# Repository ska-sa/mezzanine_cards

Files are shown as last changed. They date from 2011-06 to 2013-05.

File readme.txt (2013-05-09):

This repository contains the various daughter card designs that mate with ROACH2's high-speed MGT mezzanine connector.

Contents:
SFPP -- a 4 x SFP+ 10GbE connector board, driven by two dual Vitesse PHYs.
CX4  -- a 3 x CX4 port connector board, purely passive. Due to rear panel space constraints, the fourth port is available as a header for internal connection.

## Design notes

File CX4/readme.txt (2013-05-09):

This is the repository for the CX4 mezzanine card used by ROACH2. 

Directory contents:
design -- PCB and schematic
release -- manufacturing pack, including gerbers.

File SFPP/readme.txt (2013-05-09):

This is the design repository for the 4x SFP+ 10GbE mezzanine card, as used on ROACH2.

Directory structure:
design -- Contains the schematic and PCB layout, along with some documentation used during design.
release -- manufacturing packs for the various revision boards.

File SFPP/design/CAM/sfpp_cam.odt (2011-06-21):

PCB Specification

Date: | 15th June 2011
Company: | SKA SA
Billing Address: | 17 Baker St, Rosebank, Johannesburg, South Africa PO Box 522940, Saxonwold, 2132
Postal Address: | SKA SA, 3rd Floor, The Park, Park Road, Pinelands, 7405, South Africa
Contact: | David George | Email: | david.george@ska.ac.za
| | Tel: | +27 11 442 2434
| Philip Gibbs | Email: | philip.gibbs@ska.ac.za
| | Tel: | +27 21 506 7363

Board name: | SFP+ Mezzanine Card
Revision: | 0
Release: | PRELIM

PCB Details

PCB Specifications: | IPC 6012 Class 2
Finished Board Size: | 90 x 107.4 mm
PCB Type: | Multi-layer
Layer Count: | 8
Dielectric: | All dielectric layers to be Isola 370HR high temperature laminate
Nominal board Thickness: | 1.6mm; tolerance +/-10%
Hole tolerance: | +3mil for vias; +/- 3mil for component holes and slots
Finish: | ENIG
Soldermask: | Green
Silkscreen: | White
Minimum clearance: | 4 mil in BGA areas, 6 mil otherwise
Handling rails: | TBD
Panelisation: | TBD

PCB Stackup

Layer | # | Copper (oz) | Dieletric (mil)** | Filename
Pastemask Top | | - | - | sfpp.GTP
Silkscreen Top | | - | - | sfpp.GTO
Soldermask Top | | - | - | sfpp.GTS
Signal Top | 1 | 0.5 | | sfpp.GTL
| | | 5mil
Ground 1 | 2 | 0.5 | | sfpp.GP1
| | | 8mil
Signal 1 | 3 | 0.5 | | sfpp.G1
| | | 8mil
Power 1 | 4 | 0.5 | | sfpp.GP2
| | | *
Power 2 | 5 | 0.5 | | sfpp.G2
| | | 8mil
Signal 2 | 6 | 0.5 | | sfpp.GP3
| | | 8mil
Ground 2 | 7 | 0.5 | | sfpp.GP4
| | | 5mil
Signal Bottom | 8 | 0.5 | | sfpp.GBL
Soldermask Bottom | | - | - | sfpp.GBS
Silkscreen Bottom | | - | - | sfpp.GBO
Pastemask Bottom | | - | - | sfpp.GBP

* Thickness may be adjusted to achieve nominal total thickness previously specified, to satisfy impedance targets and to accommodate manufacturing processes.

Impedance Controlled Traces

All impedance matching to +/- 10%

Microstrip

Layers: | Signal Top (#1), Signal Bottom (#8)
Target Impedance: | 50 ohm
Trace thickness: | 8 mil

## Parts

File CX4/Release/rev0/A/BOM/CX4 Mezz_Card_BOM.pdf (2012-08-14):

Comment | Description | Designator | Footprint | Manufacturer | PartNum | Quantity
0.01uF | 0.01uF, Ceramic Capacitor | C2, C6, C7, C11, C15, C16,
| | C20, C24, C25 | CAPC1005X55L | MURATA | GRM155R71E103KA01D | 9
0.1uF | 0.1uF, Ceramic Capacitor | C3, C8, C9, C10, C12, C17,
C18, C19, C21, C26, C27, C28 CAPC1005X60L | VENKEL | C0402X7R160-104KN | 12
4.7uF | 4.7uF, Ceramic Capacitor | C4, C13, C22 | CAPC2012X127L | MURATA | GRM21BR61E475KA12K | 3
22uF | 22uF, Ceramic Capacitor | C5, C14, C23, C29, C30 | CAPC3225X270L | MURATA | GRM32ER61E226ME15L | 5
SML-LX1206IC-TR | Red, Surface mount, LED, 1206 | DS1, DS2, DS3 | LEDC3216X120N | LUMEX | SML-LX1206IC-TR | 3
QFSS-064-04.25-L-D-A-DP | Shielded, 64-Differential Pair, Rugged High-Speed
| Terminal Strip, 0.635mm Pitch | J1 | SAMTEC_QFSS-064-04.25-L-
| | | D-DP-A | SAMTEC | QFSS-064-04.25-L-D-A-DP | 1
FCN-268D008-G/2D | CX4/Infiniband 4 channel Socket Connector | J2, J3, J4 | FCN-268D008-G | Fujitsu | FCN-268D008-G/0D | 3
SMT Header, 2mm 10X2 | 2x10, 2mm Pitch, Male Header, Surface Mount | P1, P2, P3 | HEADER 10x2, SMT, 2mm | SAMTEC | TMMH-110-05-T-DV | 3
150R | 150R, 1.1mm x 0.5mm, Thick Film Resistor | R1, R5, R11 | RESC1005X40L | ROYALOHM | 0402WGJ0151T1E | 3
5K1 | 5K1, 1.1mm x 0.5mm, Thick Film Resistor | R2, R8, R12 | RESC1005X40L | ROYALOHM | 0402WAJ0512T1E | 3
3K9 | 3K9, 1.1mm x 0.5mm, Thick Film Resistor | R3, R6, R9, R13, R15, R17 | RESC1005X40L | ROYALOHM | 0402WGJ0392T1E | 6
6K8 | 6K8, 1.1mm x 0.5mm, Thick Film Resistor | R4, R10, R14 | RESC1005X40L | ROYALOHM | 0402WGJ0682T1E | 3
10K | 10K, 1.1mm x 0.5mm, Thick Film Resistor | R7, R16, R18 | RESC1005X40L | ROYALOHM | 0402WGJ0103T1E | 3
CCLD-023-25-156.250 | 156.25 MHz, Low-Jitter Differential LVDS Clock Oscillator | U1 | CCLD-023X-XX-XXX_XXX | Crystek | CCLD-023-25-156.250 | 1
MAX9032AKA | Dual Single-Supply Comparator | U2, U5, U7 | TSOT-23-8 | MAXIM | MAX9032AKA | 3
SN74AHC1G08DCKR | Single 2-Input Positive-AND Gate | U3, U6, U8 | SC70-5 | Texas Instruments | SN74AHC1G08DCKR | 3
TPS2031D | Power-Distribution Switch | U4, U9, U10 | SOIC150-8_N | Texas Instruments | TPS2031D | 3

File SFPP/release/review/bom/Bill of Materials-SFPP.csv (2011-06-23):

POD number | Manufacturer | PartNum | Description | Designator | Quantity | Rating | Tolerance | Value
TRANS-NFET-0 | Fairchild Semiconductor | BSS138 | N-Channel Logic Level Enhancement Mode Field Effect Transistor | Q1, Q4, Q5 | 3 | 0.22A
RESN-CLK-6 | Kyocera | KC7050P156.250L30E00 | 156.25 MHz, Low-Jitter Differential LVDS Clock Oscillator, 7x5mm surface mount | U6, U8 | 2
RES-TF-46 | STACKPOLE | RMC0402FT2K87 | 2K87, 1.1mm x 0.5mm, Thick Film Resistor | R6 | 1 | 0.0625W | 1% | 2k87
RES-TF-45 | STACKPOLE | RMC0402FT3K57 | 3K57, 1.1mm x 0.5mm, Thick Film Resistor | R5 | 1 | 0.0625W | 1% | 3k57
RES-TF-36 | ROYALOHM | 0402WGF2K49T1E | 2K49, 1.1mm x 0.5mm, Thick Film Resistor | R2, R45 | 2 | 0.0625W | 1% | 2K49
RES-TF-19 | ROYALOHM | 0402WGF0201T1E | 200R, 1.1mm x 0.5mm, Thick Film Resistor | R36, R37, R38, R39 | 4 | 0.0625W | 1% | 200R
RES-TF-13 | ROYALOHM | 0402WGF4991T1E | 4K99, 1.1mm x 0.5mm, Thick Film Resistor | R3, R46 | 2 | 0.0625W | 1% | 4K99
RES-TF-7 | ROYALOHM | 0402WGJ0332T1E | 3K3, 1.1mm x 0.5mm, Thick Film Resistor | R7, R8, R9, R10, R11, R12, R13, R14, R15, R16, R17, R18, R20, R21, R22, R23, R24, R25, R26, R27, R28, R29, R30, R31, R32, R33, R34, R35, R40, R41, R42, R43, R47, R48, R49, R50, R51, R52, R53, R54, R55, R56, R57, R58, R59, R60, R61, R62, R63 | 49 | 0.0625W | 5% | 3K3
RES-TF-5 | ROYALOHM | 0402WGJ0103T1E | 10K, 1.1mm x 0.5mm, Thick Film Resistor | R1, R4, R44 | 3 | 0.0625W | 5% | 10K
RES-TF-0 | ROYALOHM | 0402WG00000T1E | 0R, 1.1mm x 0.5mm, Thick Film Resistor | R19 | 1 | 0.0625W | 0% | 0R
OPTO-LPIPE-1 | Dialight | 515-1094F | 2-High, press-fit, 3mm round, light-pipe | DS1, DS2 | 2 | NA
OPTO-LED-0 | LUMEX | SML-LX1206GC-TR | Green, Surface mount, LED, 1206 | DS3, DS4, DS5, DS6 | 4 | 20mA
IND-FB-1 | Murata | BLM31PG121SN1 | 120 Ohm, Chip Ferrite Brad | L1, L2, L3, L4, L5, L6 | 6 | 3000mA | 25% | 120R
IC-REG-5 | Texas Instruments | TPS74401 | 3.0A Ultra-LDO with Programmable Soft-Start | U3, U4, U9 | 3
IC-PHY-2 | Vitesse | VSC8488XJU | DualChannel WAN/LAN/Backplane XAUI to SFP+/KR Transceiver | U1, U2 | 2
IC-MEM-5 | Atmel | AT24C1024BN-SH-B | 1M, SOIC-8, Serial EEPROM | U5, U7 | 2
CONN-PCB-27 | Molex | 74441-0001 | 20 Circuit, 0.8mm pitch SFP+ host connector | P2, P3, P4, P5 | 4
CONN-PCB-26 | Molex | 0747540420 | SFP+ 1X4 Cage Assembly | P1 | 1
CONN-PCB-19 | SAMTEC | QFSS-064-04.25-L-D-A-DP | Shielded, 64-Differential Pair, Rugged High-Speed Terminal Strip, 0.635mm Pitch | J1 | 1
CONN-PCB-16 | SAMTEC | TSM-107-01-TM-DV-P | 2x7, 2.54 mm Pitch, Male Header | P6 | 1
CAP-CER-13 | TDK | C3225X5R0J107M | 100uF, 1210, Ceramic Capacitor | C33, C42, C73 | 3 | 6.3V | 20% | 100uF
CAP-CER-8 | MURATA | GRM21BR61C105KA01L | 1uF, Ceramic Capacitor | C71, C72, C74, C75, C76, C77, C78, C112, C113, C115, C116, C117, C118, C119 | 14 | 16V | 10% | 1uF
CAP-CER-6 | MURATA | GRM155R71E103KA01D | 0.01uF, Ceramic Capacitor | C38, C44, C128 | 3 | 25V | 10% | 0.01uF
CAP-CER-5 | MURATA | GRM32DR61E106KA12L | 10uF, Ceramic Capacitor | C34, C36, C37, C39, C40, C43, C124, C126, C127 | 9 | 25V | 10% | 10uF
CAP-CER-3 | MURATA | GRM21BR61E475KA12K | 4.7uF, Ceramic Capacitor | C45, C46, C47, C48, C56, C57, C58, C61, C82, C83, C84, C85, C94, C95, C103, C104 | 16 | 25V | 10% | 4.7uF
CAP-CER-1 | VENKEL | C0402X7R160-104KN | 0.1uF, Ceramic Capacitor | C1, C2, C3, C4, C5, C6, C7, C8, C9, C10, C11, C12, C13, C14, C15, C16, C17, C18, C19, C20, C21, C22, C23, C24, C25, C26, C27, C28, C29, C30, C31, C32, C35, C41, C49, C50, C51, C52, C53, C54, C55, C59, C60, C62, C63, C64, C65, C66, C67, C68, C69, C70, C79, C80, C81, C86, C87, C88, C89, C90, C91, C92, C93, C96, C97, C98, C99, C100, C101, C102, C105, C106, C107, C108, C109, C110, C111, C114, C120, C121, C122, C125, C129, C130, C131 | 85 | 16V | 10% | 0.1uF

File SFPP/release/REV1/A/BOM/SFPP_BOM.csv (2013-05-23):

POD number | Manufacturer | PartNum | Description | Designator | Tolerance | Value | Quantity
CAP-CER-1 | VENKEL | C0402X7R160-104KN | 0.1uF, Ceramic Capacitor | C1, C2, C3, C4, C5, C6, C7, C8, C9, C10, C11, C12, C13, C14, C15, C16, C17, C18, C19, C20, C21, C22, C23, C24, C25, C26, C27, C28, C29, C30, C31, C32, C35, C41, C49, C50, C51, C52, C53, C54, C55, C59, C60, C62, C63, C64, C65, C66, C67, C68, C69, C70, C79, C80, C82, C85, C86, C87, C88, C89, C90, C91, C92, C93, C96, C97, C98, C99, C100, C101, C102, C105, C106, C108, C110, C111, C114, C120, C121, C125, C129, C130, C131, C133, C136, C141, C144 | 10% | 0.1uF | 87
CAP-CER-13 | TDK | C3225X5R0J107M | 100uF, 1210, Ceramic Capacitor | C33, C42, C73, C145 | 20% | 100uF | 4
CAP-CER-5 | MURATA | GRM32DR61E106KA12L | 10uF, Ceramic Capacitor | C34, C36, C37, C39, C40, C43, C124, C126, C127, C142, C143, C146 | 10% | 10uF | 12
CAP-CER-6 | MURATA | GRM155R71E103KA01D | 0.01uF, Ceramic Capacitor | C38, C44, C81, C122, C128, C139, C140, C147 | 10% | 0.01uF | 8
CAP-CER-3 | MURATA | GRM21BR61E475KA12K | 4.7uF, Ceramic Capacitor | C45, C46, C47, C48, C56, C57, C58, C61, C83, C84, C94, C95, C103, C104, C123, C132, C134, C135, C137, C138 | 10% | 4.7uF | 20
CAP-CER-8 | MURATA | GRM21BR61C105KA01L | 1uF, Ceramic Capacitor | C71, C72, C74, C75, C76, C77, C78, C112, C113, C115, C116, C117, C118, C119 | 10% | 1uF | 14
CAP-CER-4 | MURATA | GRM155R61H102KA01D | 1000pF, Ceramic Capacitor | C107, C109 | 10% | 1000pF | 2
OPTO-LPIPE-1 | Dialight | 515-1094F | 2-High, press-fit, 3mm round, light-pipe | DS1, DS2 |  |  | 2
OPTO-LED-0 | LUMEX | SML-LX1206GC-TR | Green, Surface mount, LED, 1206 | DS3, DS4, DS5, DS6 |  |  | 4
CONN-PCB-19 | SAMTEC | QFSS-064-04.25-L-D-A-DP | Shielded, 64-Differential Pair, Rugged High-Speed Terminal Strip, 0.635mm Pitch | J1 |  |  | 1
IND-FB-1 | Murata | BLM31PG121SN1 | 120 Ohm, Chip Ferrite Brad | L1, L2, L3, L4, L5, L6, L7, L8, L9, L10 | 25% | 120R | 10
IND-FB-0 | Murata | BLM21BD601SN1 | 600 Ohm, Chip Ferrite Bead | L11 | 25% | 600R | 1
CONN-PCB-26 | Molex | 747540420 | SFP+ 1X4 Cage Assembly | P1 |  |  | 1
CONN-PCB-27 | Molex | 74441-0001 | 20 Circuit, 0.8mm pitch SFP+ host connector | P2, P3, P4, P5 |  |  | 4
CONN-PCB-16 | SAMTEC | TSM-107-01-TM-DV-P | 2x7, 2.54 mm Pitch, Male Header | P6 |  |  | 1
TRANS-NFET-0 | Fairchild Semiconductor | BSS138 | N-Channel Logic Level Enhancement Mode Field Effect Transistor | Q1, Q2, Q3, Q4, Q5, Q6, Q7 |  |  | 7
RES-TF-5 | ROYALOHM | 0402WGJ0103T1E | 10K, 1.1mm x 0.5mm, Thick Film Resistor | R1, R4, R44, R66 | 5% | 10K | 4
RES-TF-36 | ROYALOHM | 0402WGF2K49T1E | 2K49, 1.1mm x 0.5mm, Thick Film Resistor | R2, R45 | 1% | 2K49 | 2
RES-TF-13 | ROYALOHM | 0402WGF4991T1E | 4K99, 1.1mm x 0.5mm, Thick Film Resistor | R3, R46 | 1% | 4K99 | 2
RES-TF-45 | STACKPOLE | RMC0402FT3K57 | 3K57, 1.1mm x 0.5mm, Thick Film Resistor | R 5 | 1% | 3k57 | 1
RES-TF-46 | STACKPOLE | RMC0402FT2K87 | 2K87, 1.1mm x 0.5mm, Thick Film Resistor | R 6 | 1% | 2k87 | 1
RES-TF-7 | ROYALOHM | 0402WGJ0332T1E | 3K3, 1.1mm x 0.5mm, Thick Film Resistor | R7, R8, R9, R10, R11, R12, R13, R14, R15, R16, R17, R18, R20, R21, R22, R23, R24, R25, R26, R27, R28, R29, R30, R31, R32, R33, R34, R35, R36, R37, R38, R39, R40, R41, R42, R43, R47, R48, R49, R50, R51, R52, R53, R54, R55, R56, R57, R58, R59, R60, R61, R62, R63, R70, R71, R72, R73 | 5% | 3K3 | 57
RES-TF-0 | ROYALOHM | 0402WG00000T1E | 0R, 1.1mm x 0.5mm, Thick Film Resistor | R19, R65 | 0% | 0R | 2
RES-TF-14 | ROYALOHM | 0402WGF0101T1E | 100R, 1.1mm x 0.5mm, Thick Film Resistor | R64, R69 | 1% | 100R | 2
RES-TF-55 | ROYALOHM | 0402WGF3601T1E | 3K6, 1.1mm x 0.5mm, Thick Film Resistor | R 67 | 1% | 3K6 | 1
RES-TF-54 | ROYALOHM | 0402WGF1601T1E | 1K6, 1.1mm x 0.5mm, Thick Film Resistor | R 68 | 1% | 1K6 | 1
IC-PHY-2 | Vitesse | VSC8488XJU | DualChannel WAN/LAN/Backplane XAUI to SFP+/KR Transceiver | U1, U2 |  |  | 2
IC-REG-5 | Texas Instruments | TPS74401RGW | 3.0A Ultra-LDO with Programmable Soft-Start | U3, U4, U9, U10 |  |  | 4
IC-LOG-14 | Micrel | SY89832UMG | 2.5 C Ultra-precision 1:4 LVDS Fanout Buffer/Translator with Interal Termination | U6 |  |  | 1
RESN-CLK-4 | Crystek | CCLD-023-25-156.250 | 2.5V 156.25 MHz, Low-Jitter Differential LVDS Clock Oscillator | U8 |  |  | 1
IC-MEM-5 | Atmel | AT24C1024BN-SH-B | 1M, SOIC-8, Serial EEPROM | U5, U7 |  |  | 2 | Discontinued
 | Atmel | AT24CM01-SSHM-B |  | U5, U7 |  |  | 2 | New Part

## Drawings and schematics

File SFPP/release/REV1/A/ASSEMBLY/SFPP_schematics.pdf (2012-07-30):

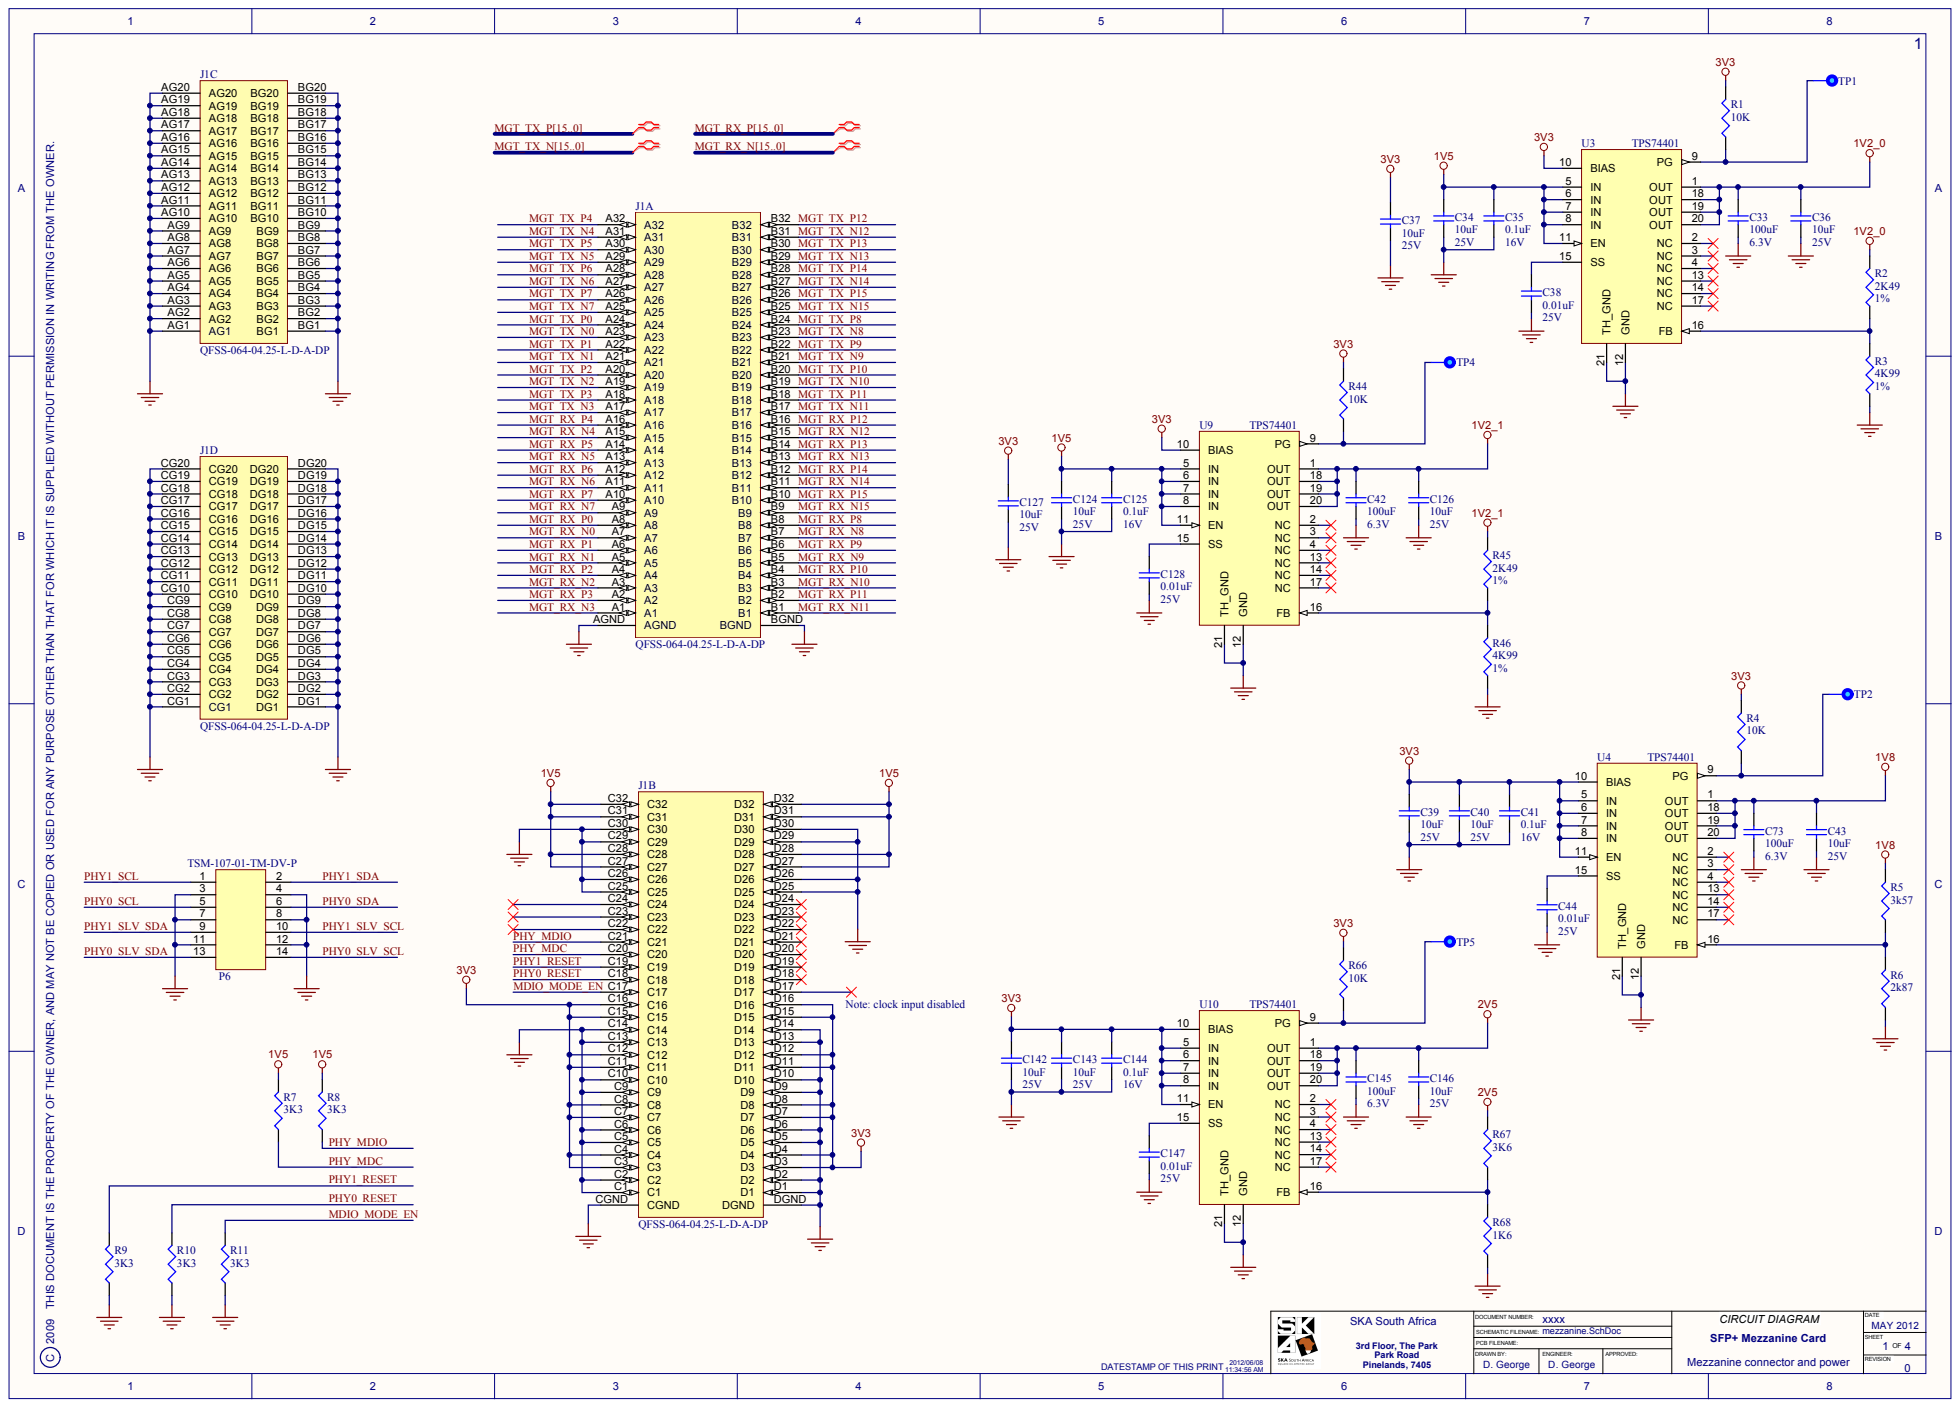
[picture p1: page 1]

2009 THIS DOCUMENT IS THE PROPERTY OF THE OWNER, AND MAY NOT BE COPIED OR USED FOR ANY PURPOSE OTHER THAN THAT FOR WHICH IT IS SUPPLIED WITHOUT PERMISSION IN WRITING FROM THE OWNER. C

EN 11 | 2

EN 11

Note: clock input disabled

D O C U M E N T N U M B E R : x x x x | CIRCUIT DIAGRAM | D A T E M A Y 2

mezzanine.SchDoc APPRO S C H E M A T I C F ILE N A M E : P C B F ILE N A M E : | S H E E T O F

D RAWN B Y : | E N G I N E E R : | V E D : | R E V I S I O N

8 DATESTAMP OF THIS PRINT

zanine connector and power

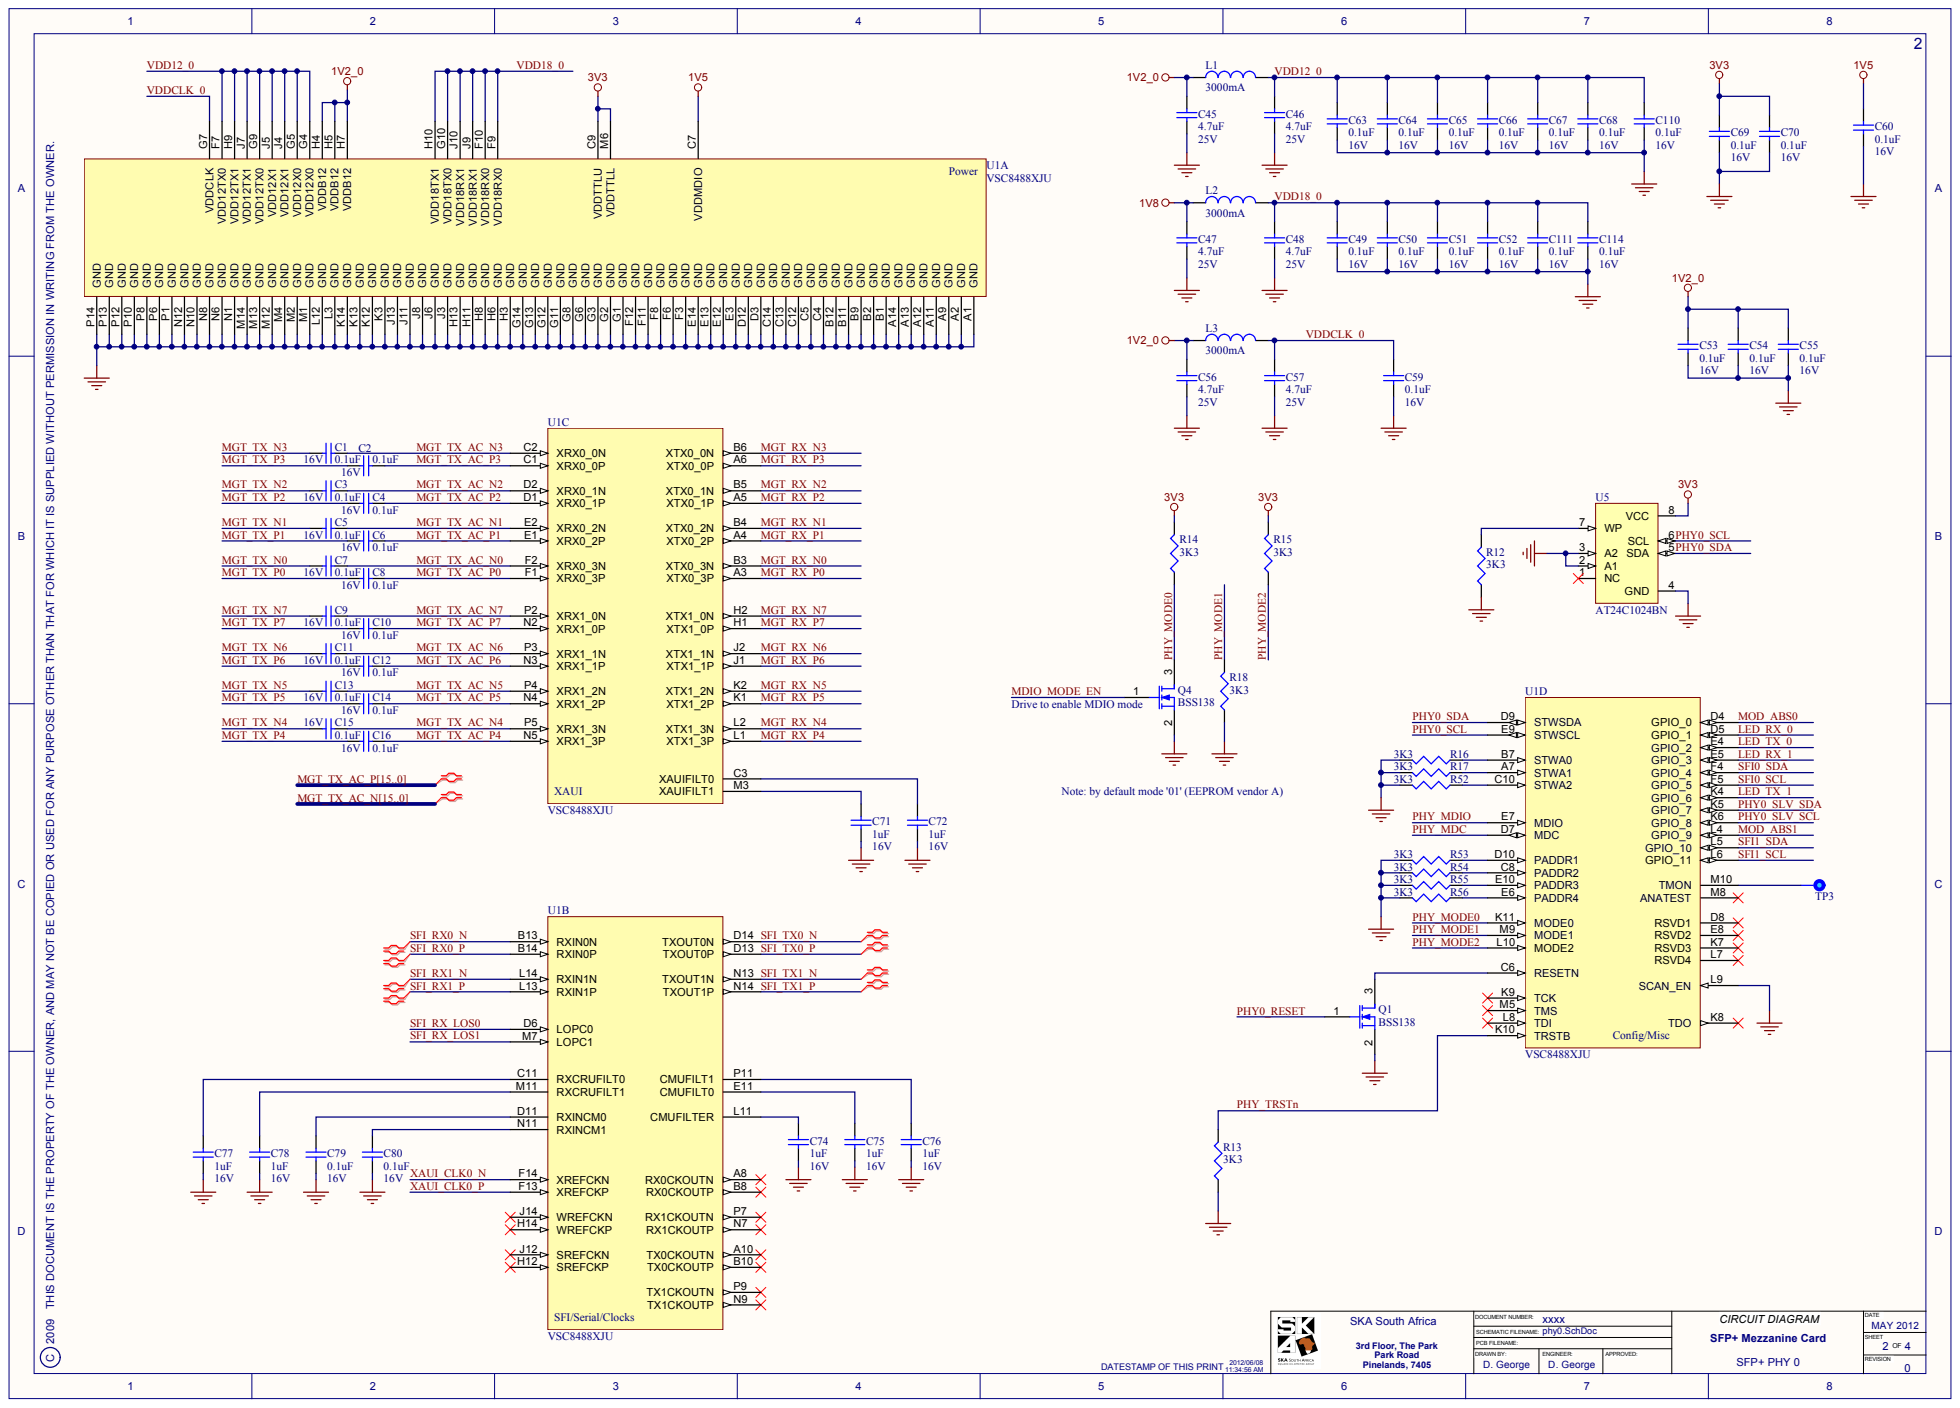
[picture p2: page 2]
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

MDIO_MODE_EN
Drive to enable MDIO mode

Note: by default mode '01' (EEPROM vendor A)

DOCUMENT NUMBER: xxxx | DATE MAY 2012

phy0.SchDoc SCHEMATIC FILENAME: PCB FILENAME: | SHEET OF 4

APPROVED: | REVISION

2012/06/08 DATESTAMP OF THIS PRINT

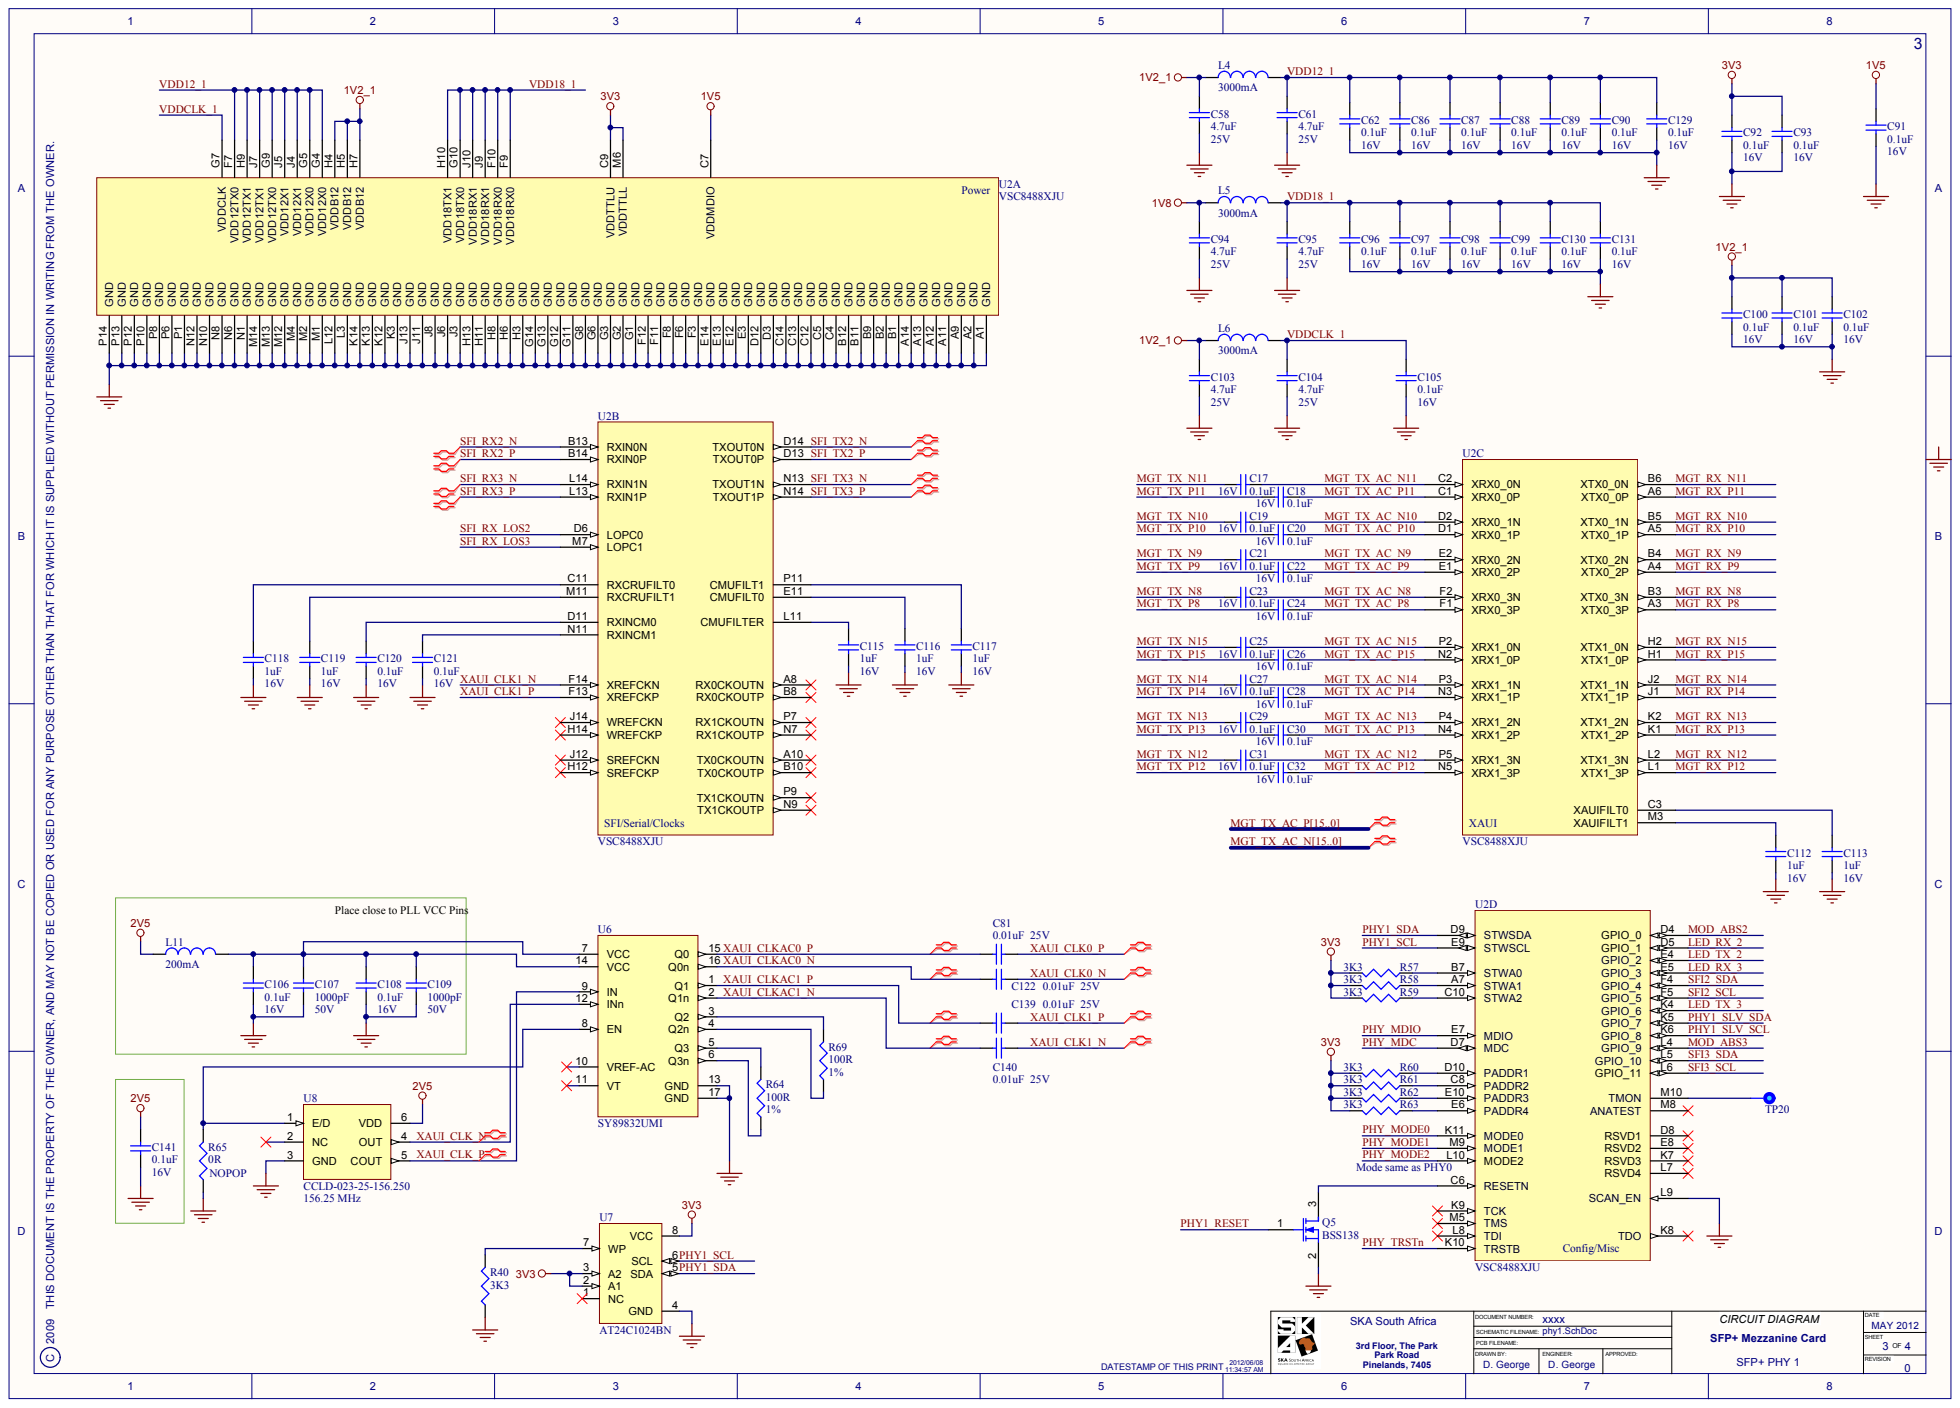
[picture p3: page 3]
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

Place close to PLL VCC Pins

NC 2 OUT | 4 | XAUI_CLK_N
GND 3 | | XAUI_CLK_P

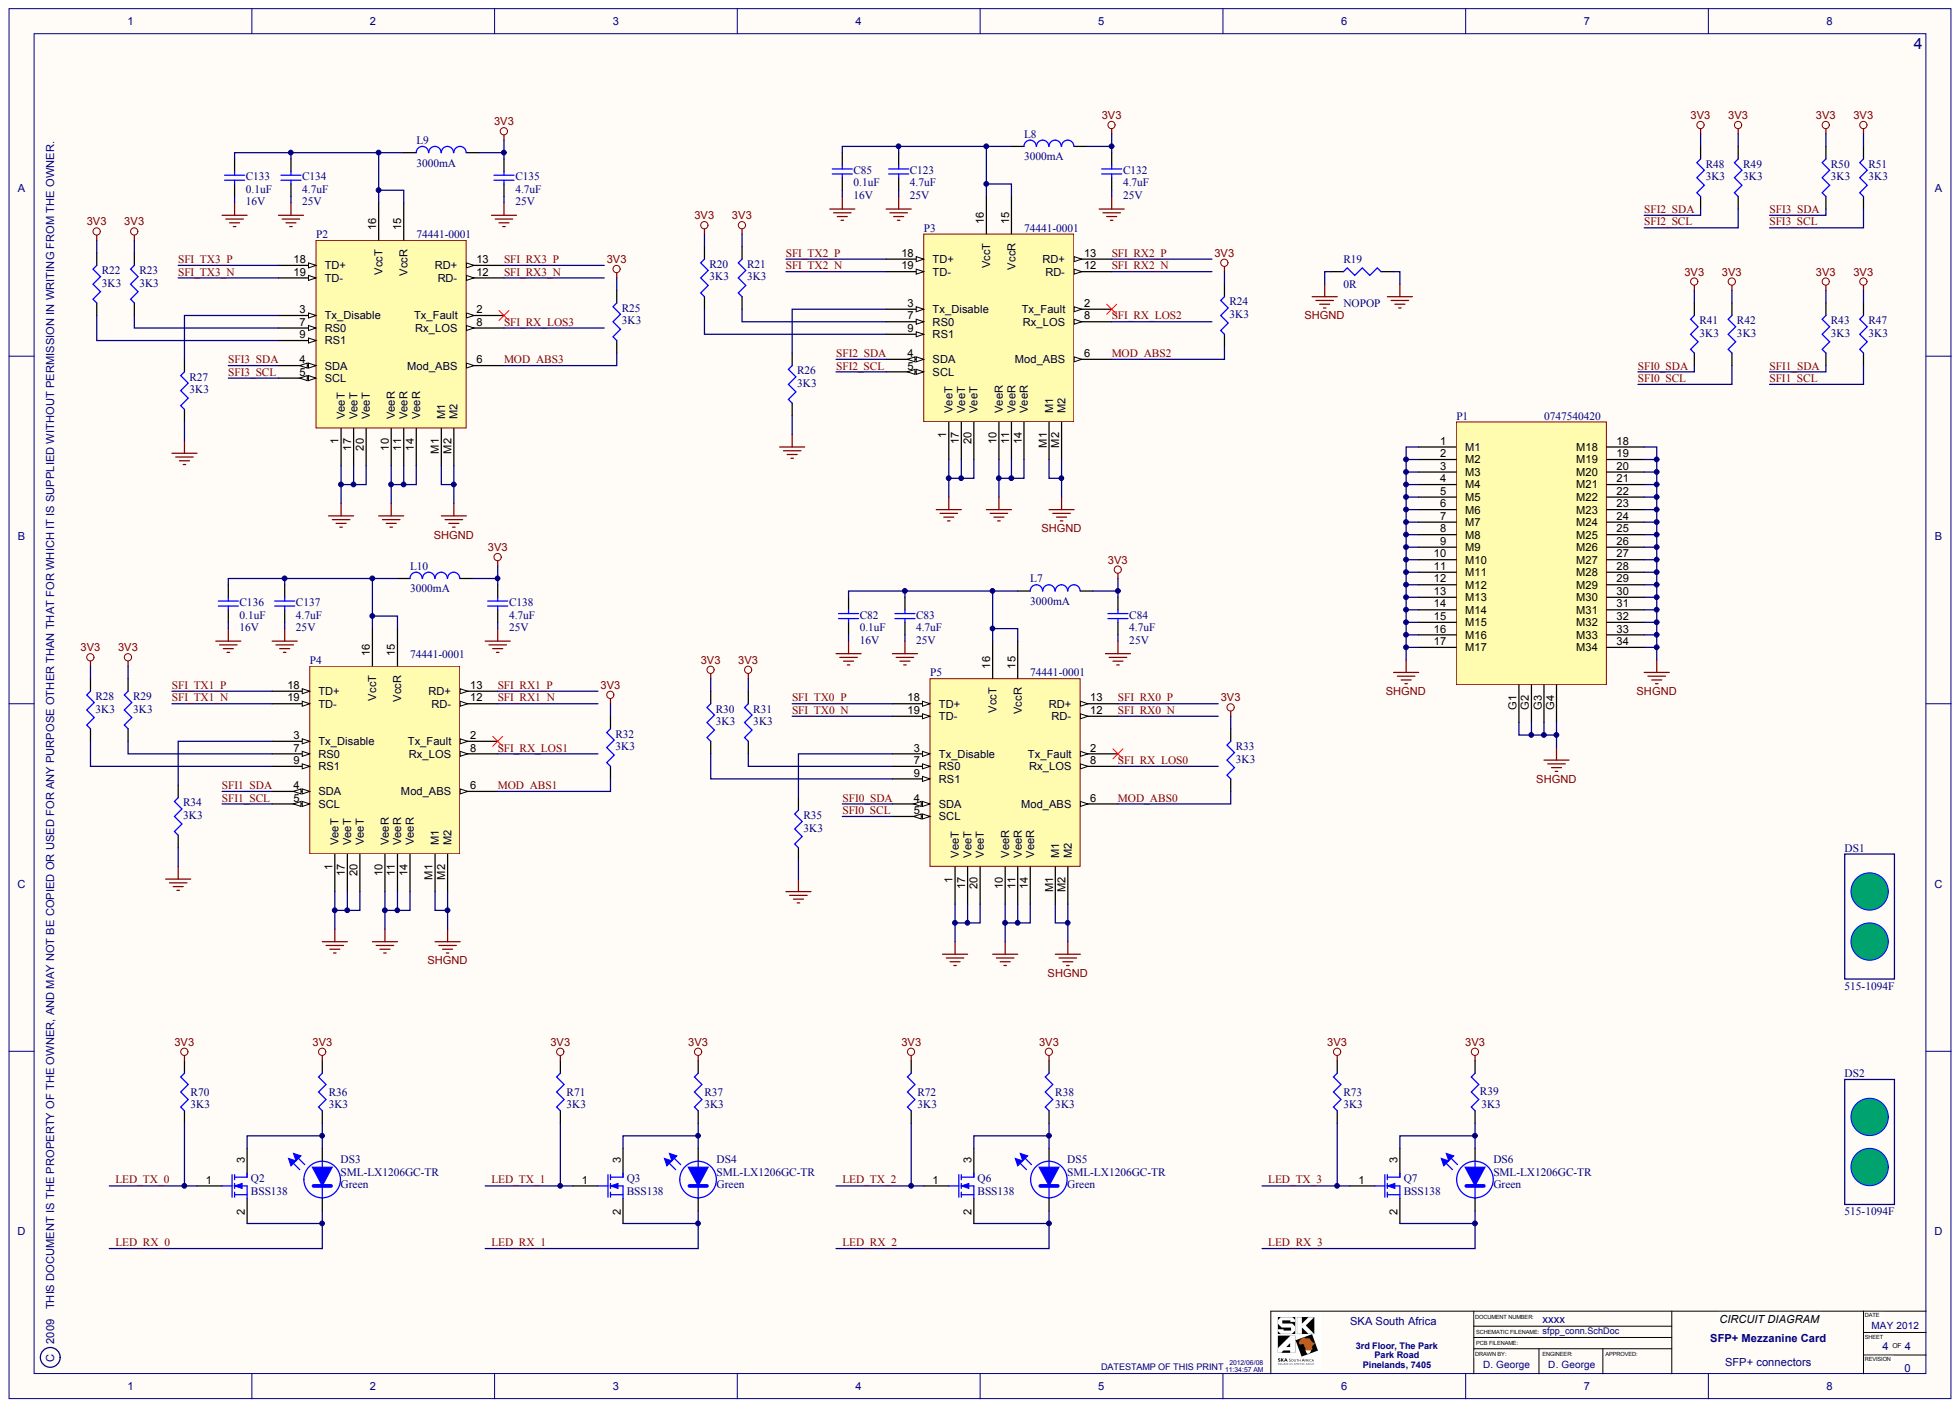
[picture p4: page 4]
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

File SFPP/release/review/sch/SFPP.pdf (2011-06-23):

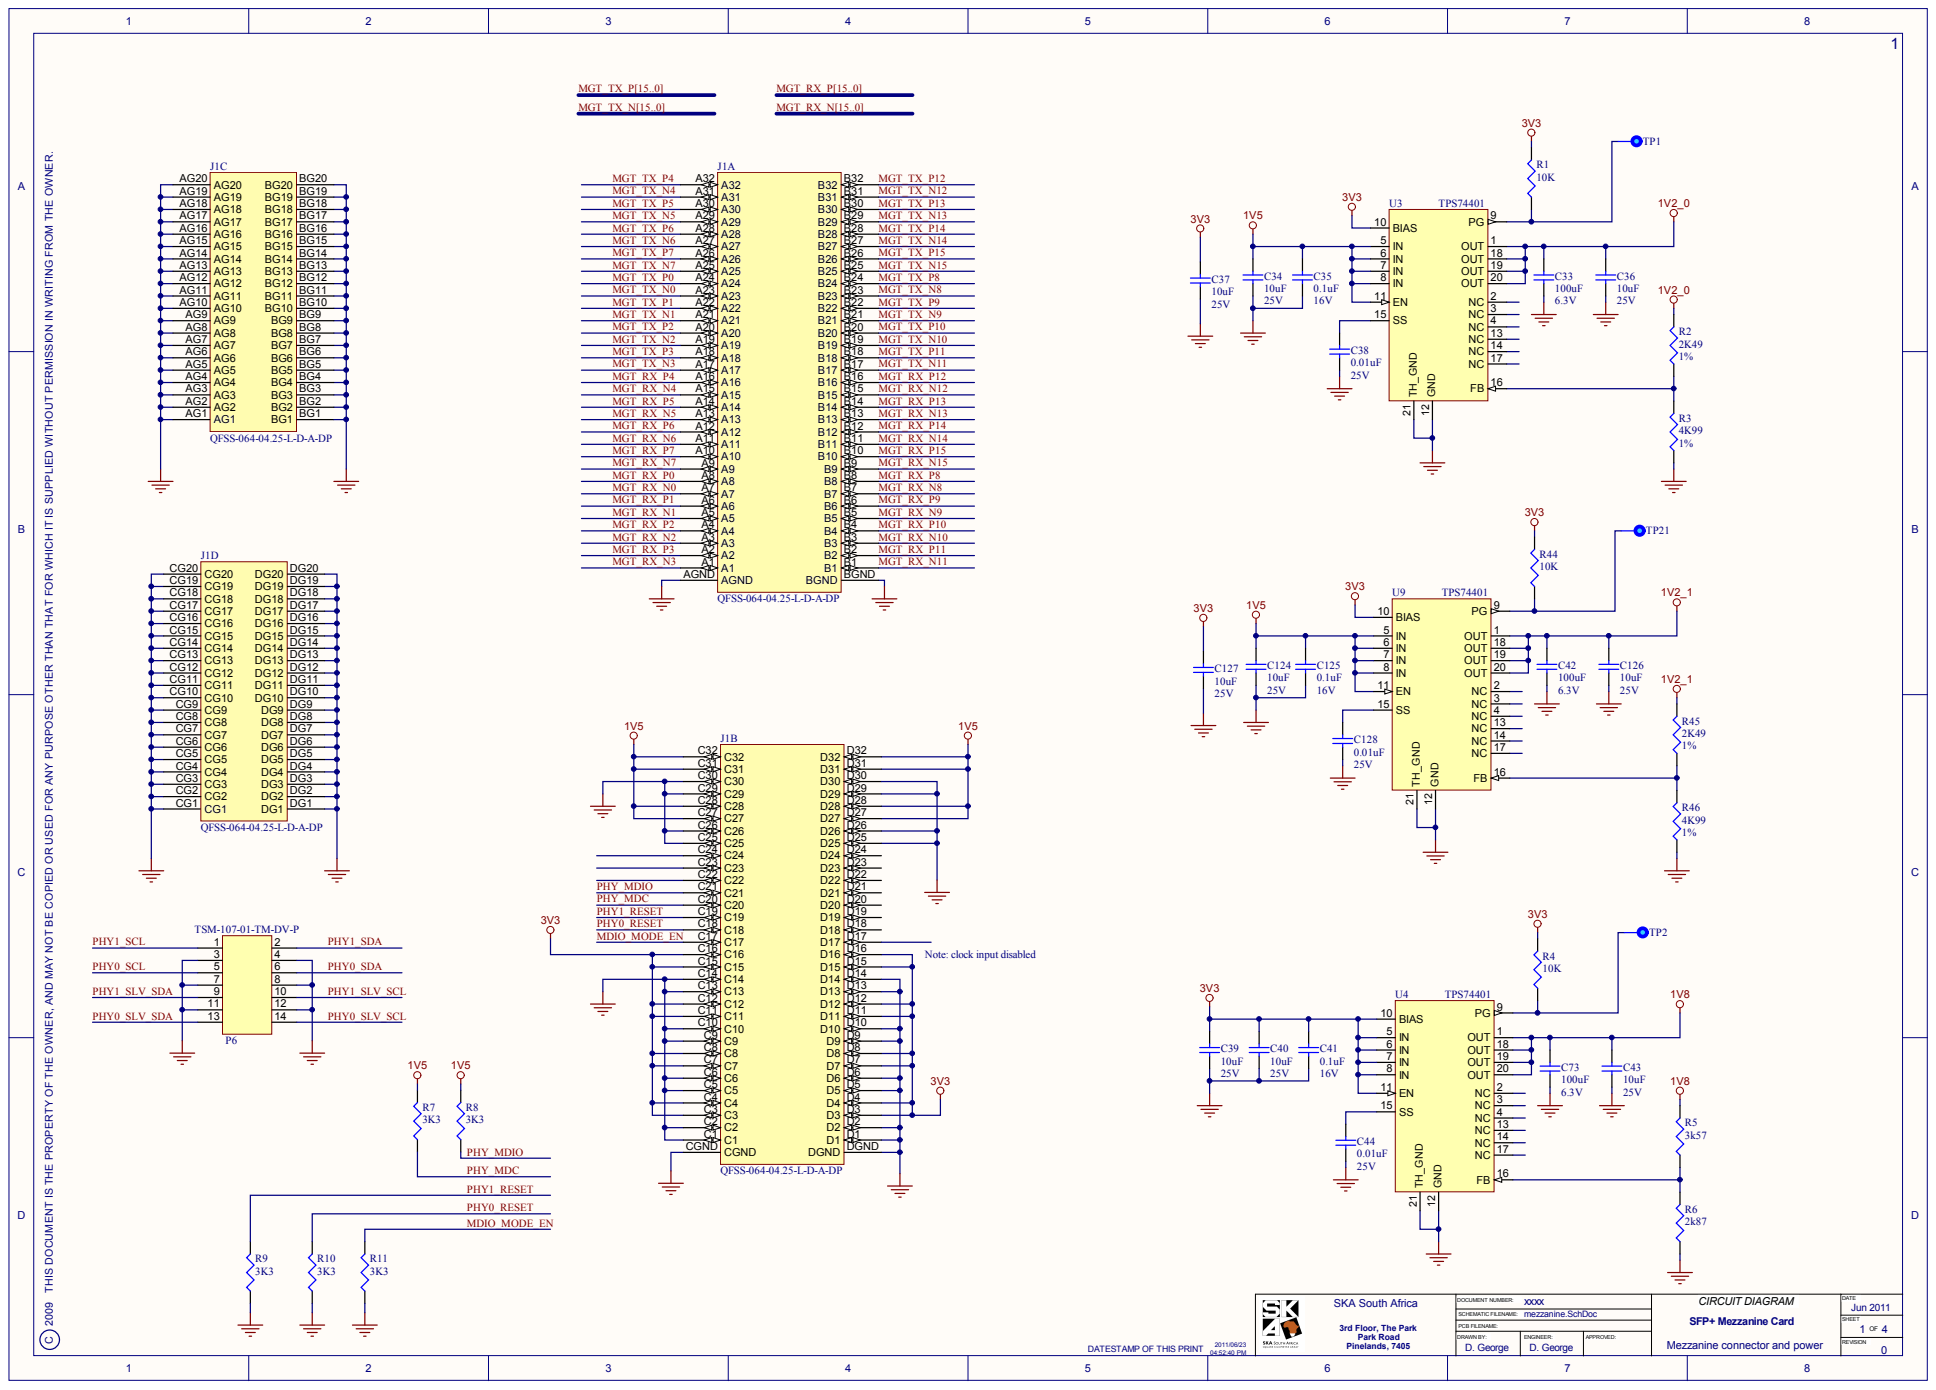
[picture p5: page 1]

2009 THIS DOCUMENT IS THE PROPERTY OF THE OWNER, AND MAY NOT BE COPIED OR USED FOR ANY PURPOSE OTHER THAN THAT FOR WHICH IT IS SUPPLIED WITHOUT PERMISSION IN WRITING FROM THE OWNER. C

EN 11 | 2

U MEN T N BER xxxx | C UI DIA G RA M | D AT E Ju

me z z a nin e . Sch o c HEM C F L AM : | S HEE T OF

RAW N BY: | NGI EER | APP VED | R V I O N

anine connector and powe

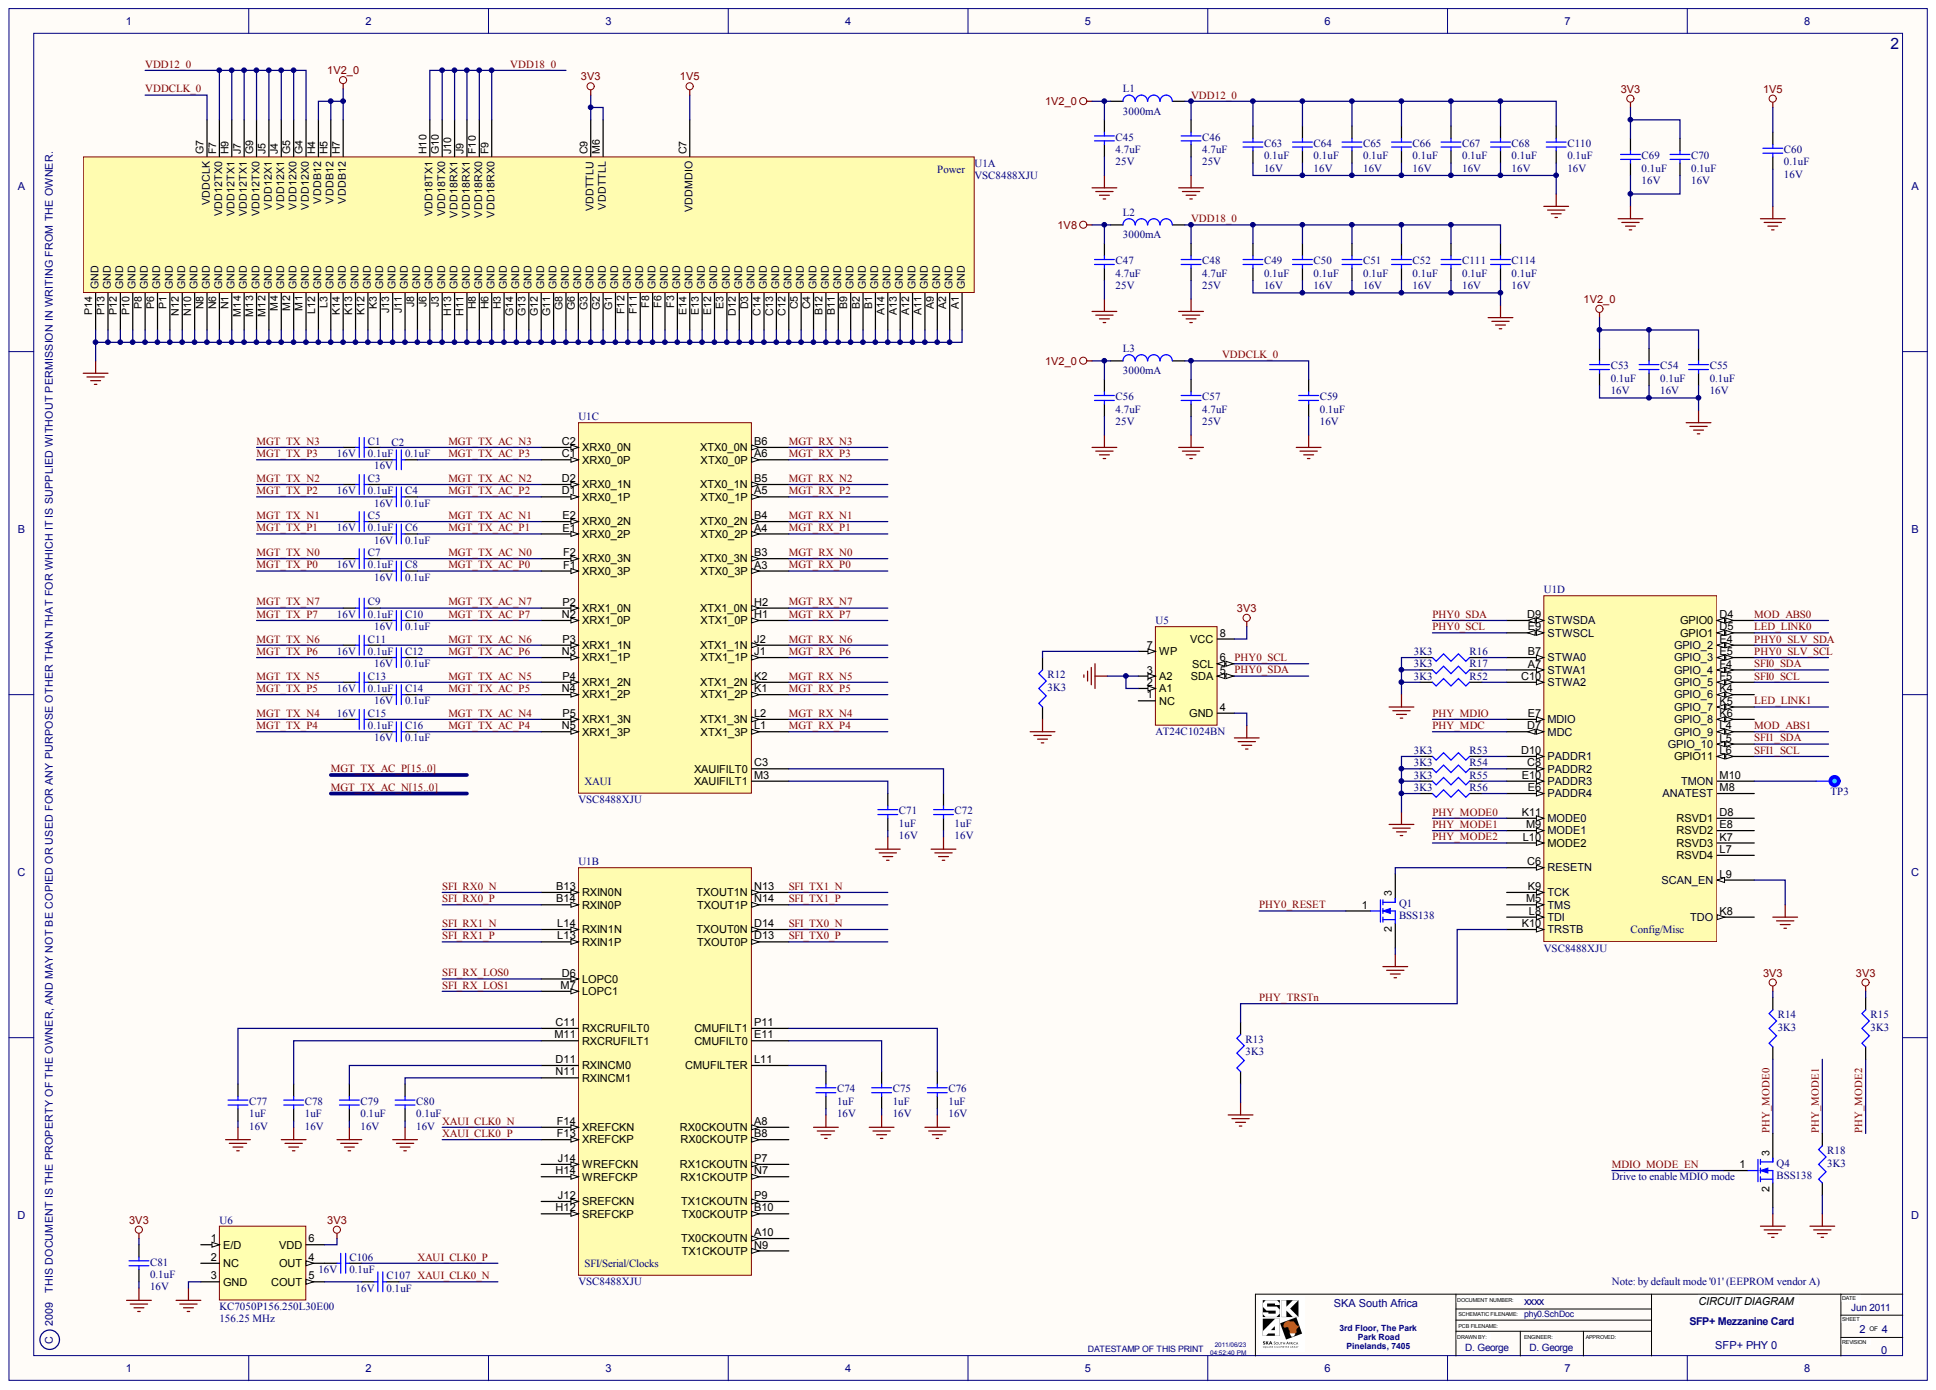
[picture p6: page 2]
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

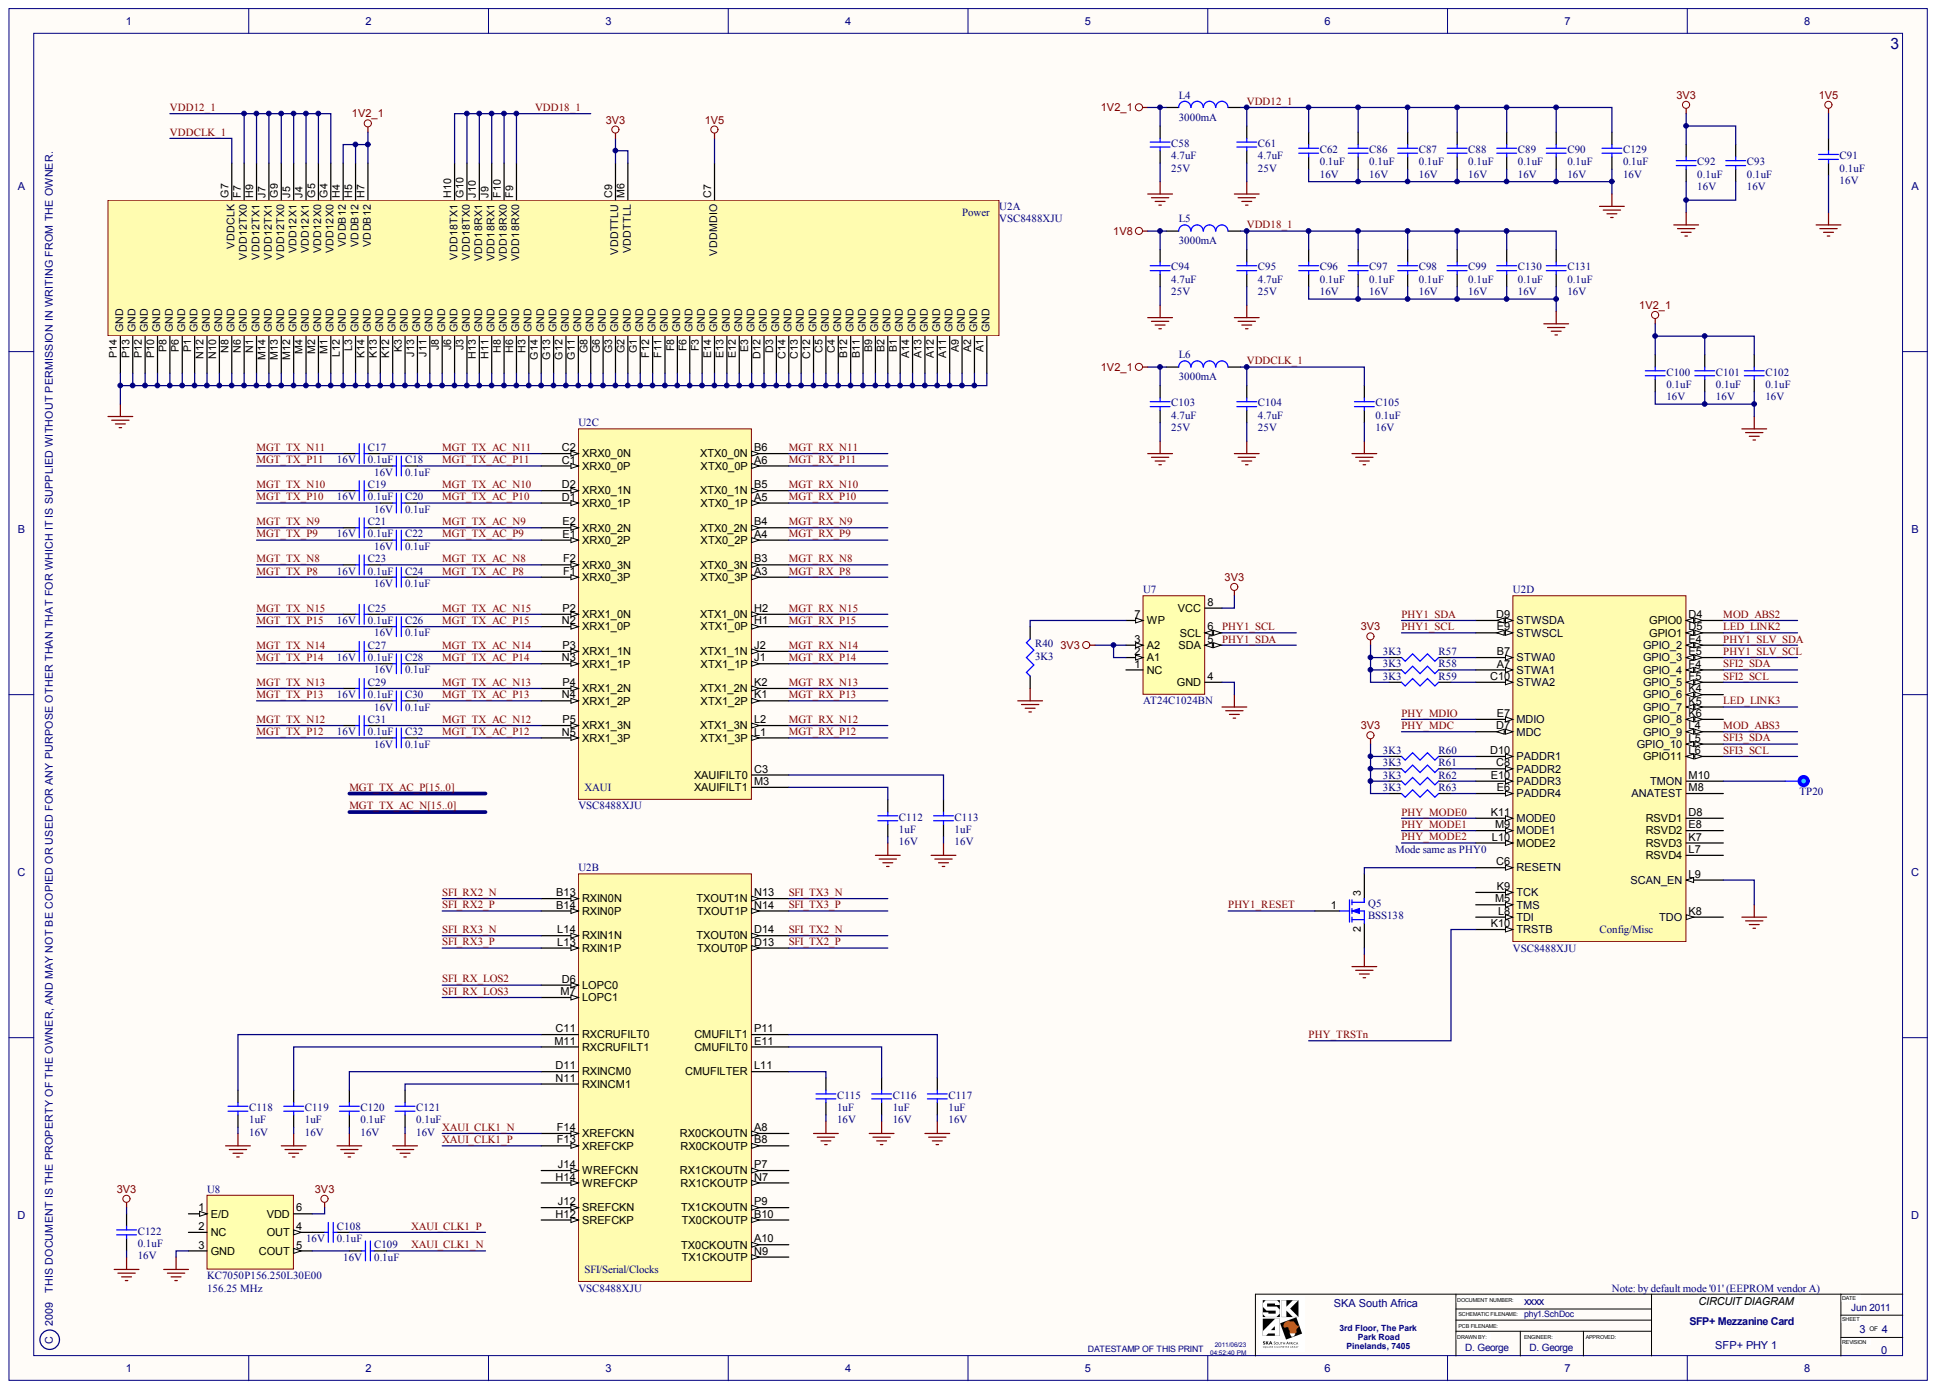
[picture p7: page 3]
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

DOCUMENT NUMBER: | CIRCUIT DIAGRAM | DATE Jun 2011

Note: by default mode '01' (EEPROM vendor A)

phy1.SchDoc SCHEMATIC FILENAME: PCB FILENAME: | SHEET OF 4

APPROVED: | REVISION

2011/06/23 DATESTAMP OF THIS PRINT

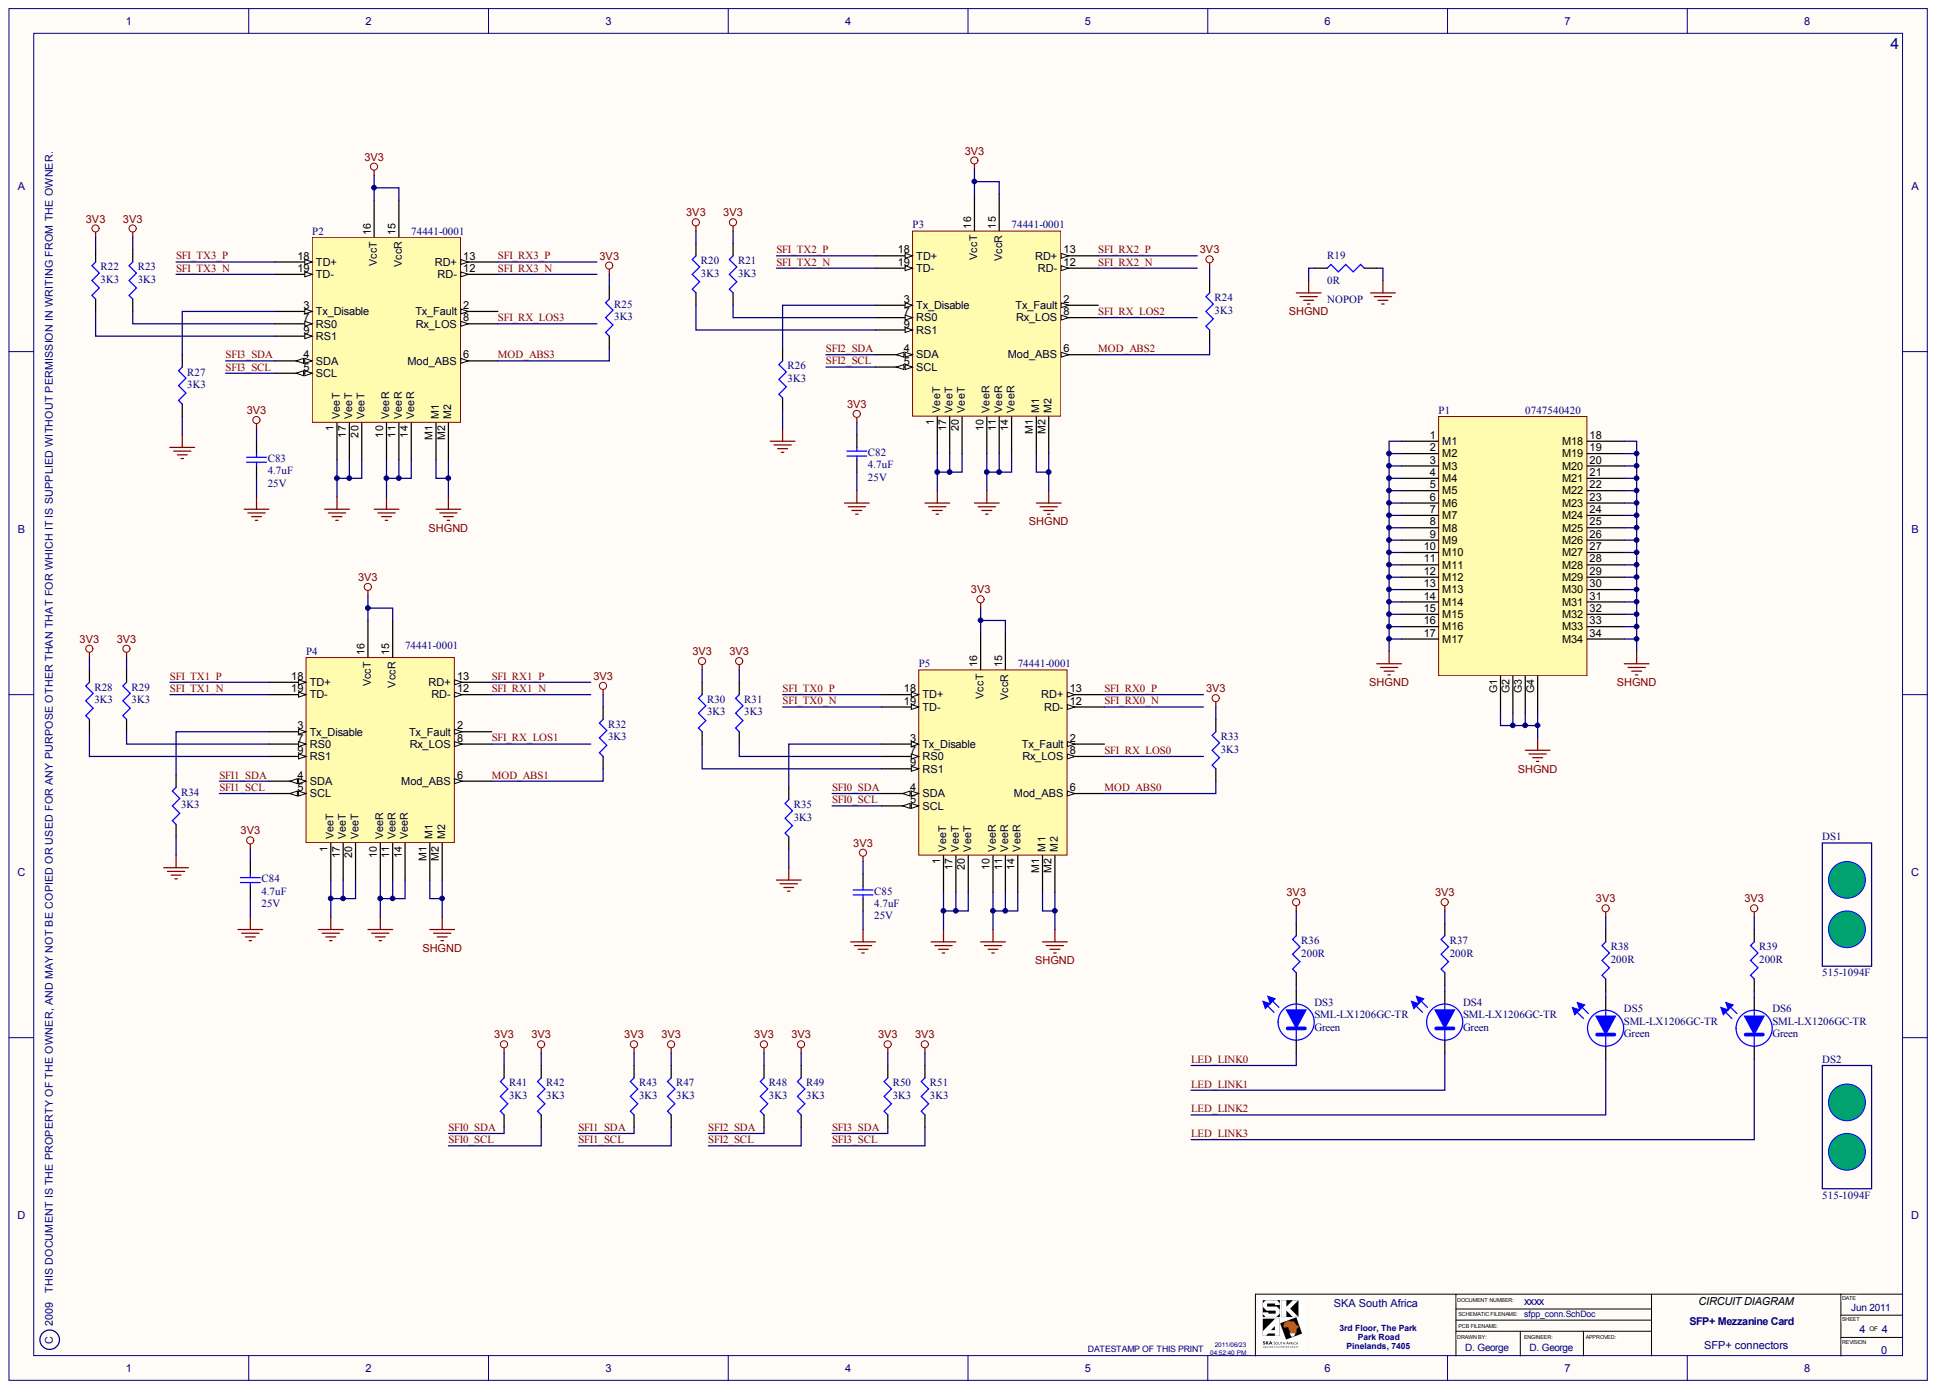
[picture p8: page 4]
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

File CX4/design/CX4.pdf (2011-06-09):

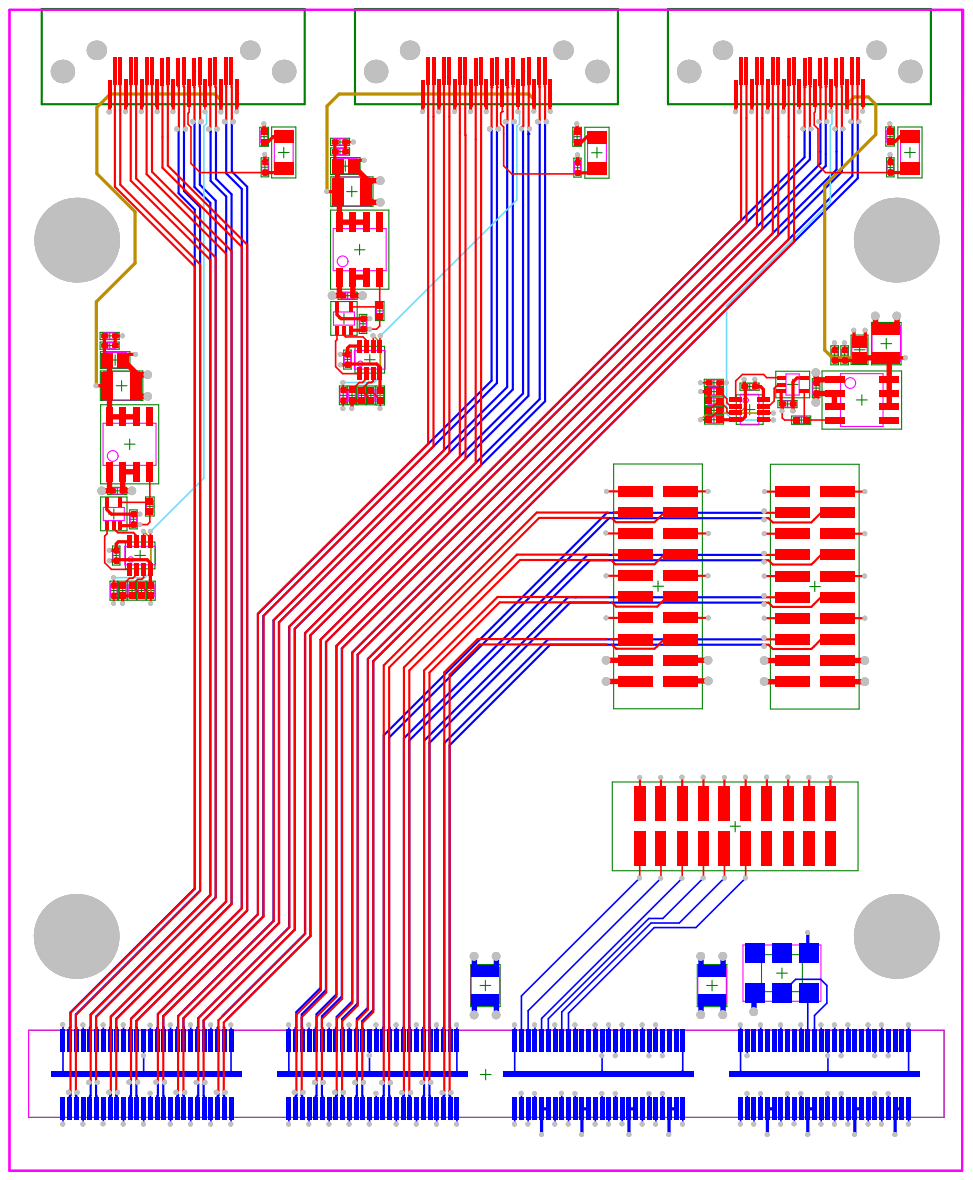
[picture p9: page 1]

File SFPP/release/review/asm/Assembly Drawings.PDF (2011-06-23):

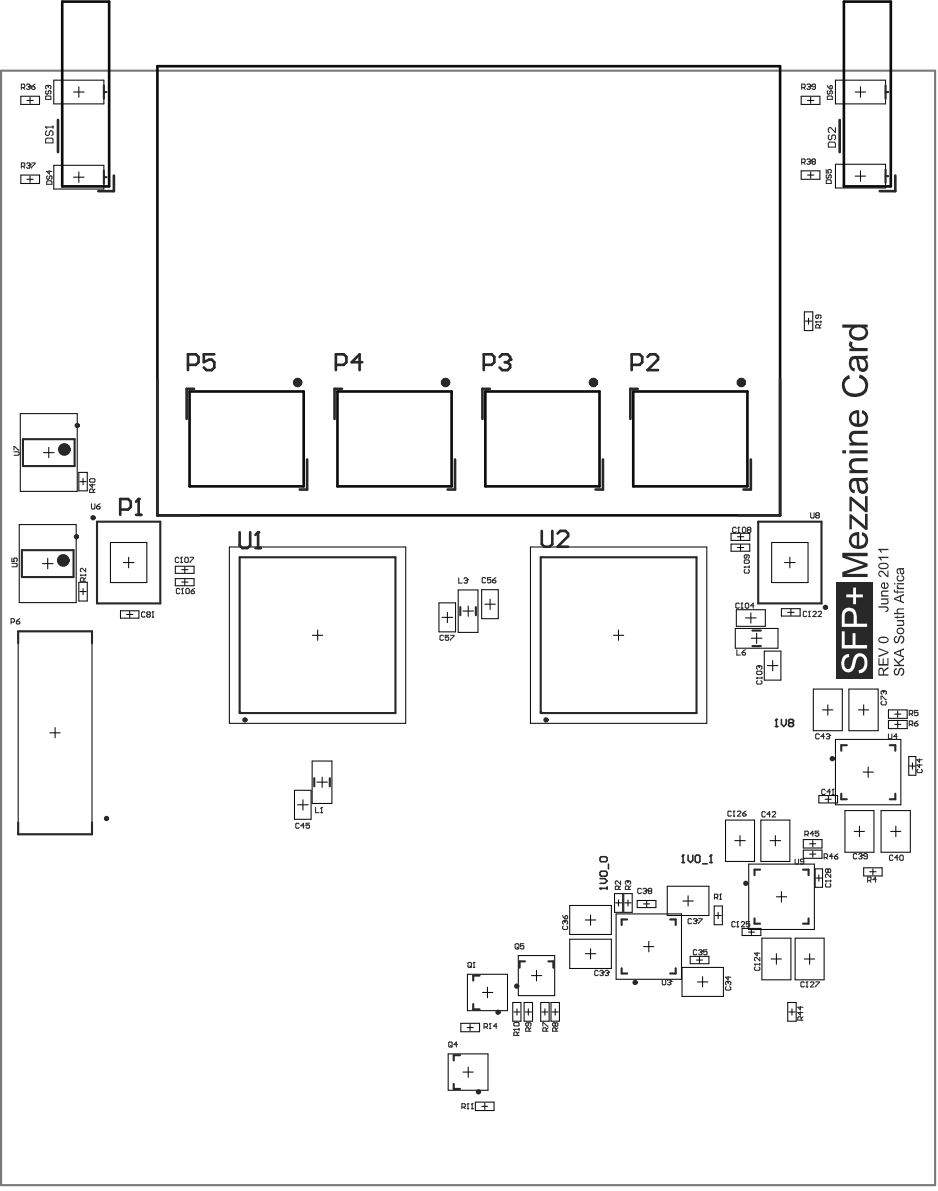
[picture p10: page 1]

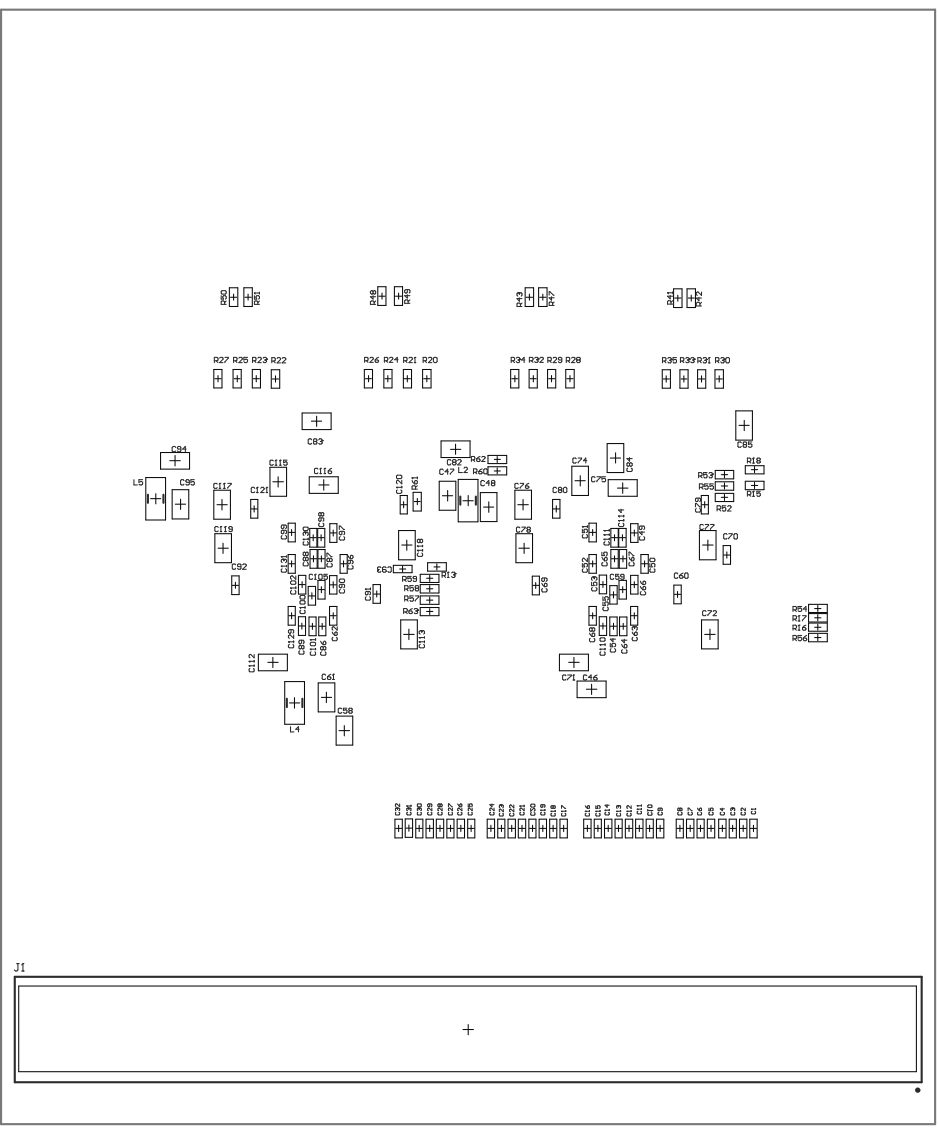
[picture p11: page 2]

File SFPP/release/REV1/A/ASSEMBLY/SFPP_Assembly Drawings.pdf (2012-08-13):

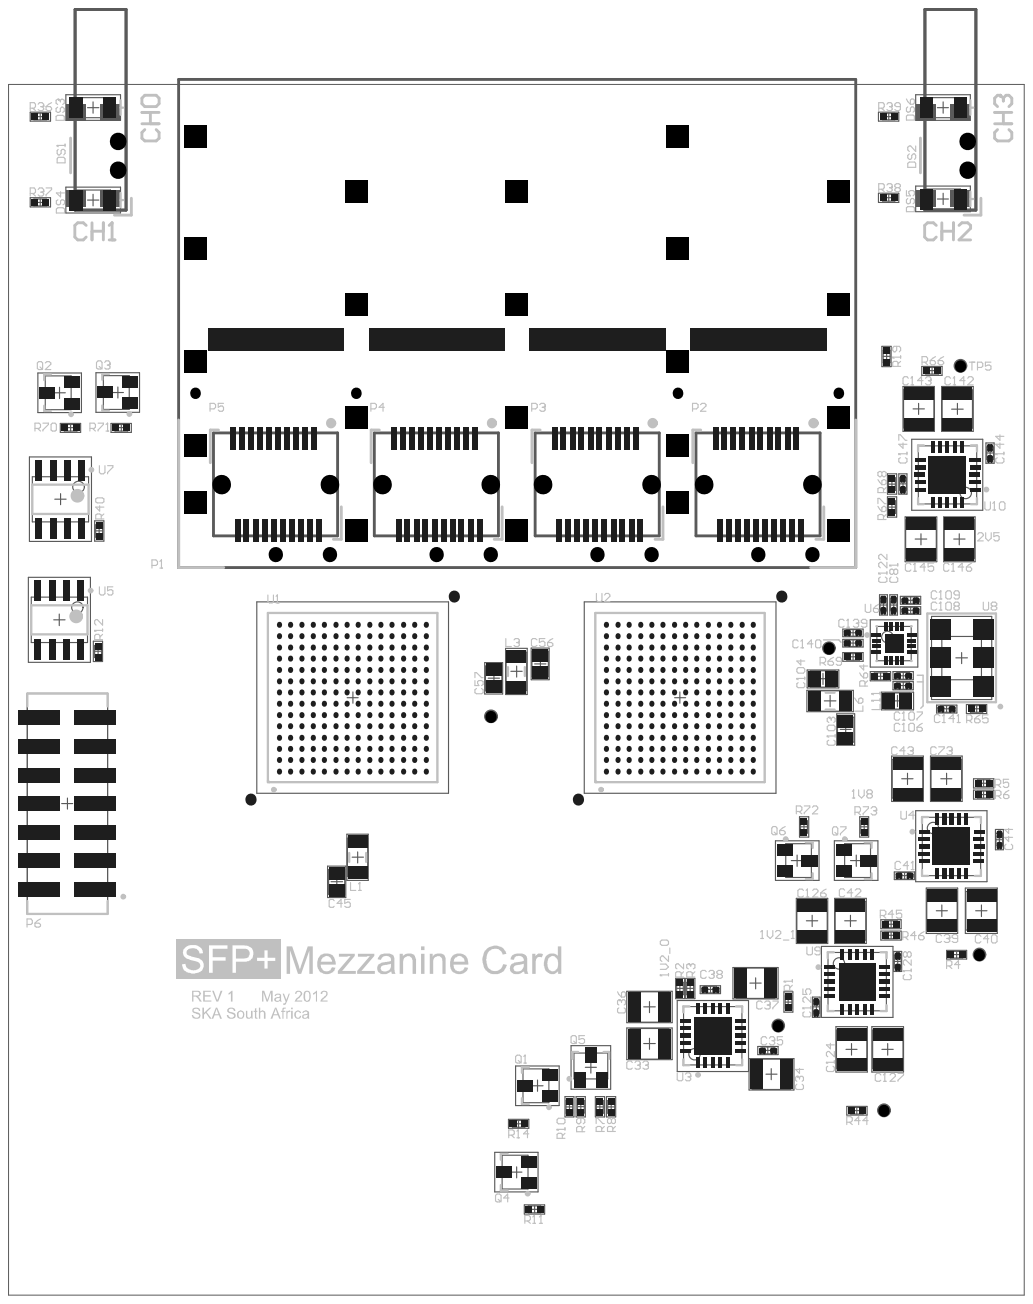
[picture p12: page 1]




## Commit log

2011-06-09 rename mezzanine card folder
    [CX4 Mezz Card.ods, CX4 Mezz Card.xls, CX4 Mezz Card_Production.xls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]
2011-06-09 Moved CX$ project to CX4 directory
    [CX4_!.PcbDoc, CX4_3port_card.SchDoc, CX4_enable_logic.SchDoc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]
2011-06-13 Added SFP+ mezzanine card project project
    [SFPP.PrjPCB, mezzanine.SchDoc, phy0.SchDoc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]
2011-06-14 schematics done placement done
    [SFPP.PrjPCB, mezzanine.SchDoc, phy0.SchDoc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]
2011-06-14 Layout first draft done
    [SFPP.PrjPCB, sfpp_conn.SchDoc]
2011-06-15 Made board 6mil clearance and 5mil track except BGA area thickened high speed traces, 5mil dielectric on top layer added i2c pullups
    [SFPP.PrjPCB, sfpp_conn.SchDoc]
2011-06-20 shortened board by 2.66mm added inductors to filter phy power supplies rerouted all single ended stuff. drcs ok
    [Mezz_Card.PrjPCB, SFPP.PrjPCB, phy0.SchDoc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]
2011-06-21 Various minor tweaks to design, added output jobs script
    [SFPP.PrjPCB, mezzanine.SchDoc, phy0.SchDoc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]
2011-06-22 added release review files
    [Bill of Materials-SFPP.csv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]
2011-06-23 SFPP commits after internal review. The following design action item were raised:
    1) Check power sequencing (EB)
    No sequencing requirement for vsc8488; no change
    2) Test points for power supplies (FK)
    Added silkscreen text for 1v2_0, 1v2_1 and 1v8
    3) Check AT24C1024's obsolescence (EB)
    No info on site. Lots of parts on online suppliers. No change.
    4) Check shielding solution (FK)
    No action yet.
    5) Replace LDO caps with 100uF ceramic (FK)
    Changed to 1210 100uf 6.3V caps.
    6) Improve SFI (10Gbps) routing (FK)
    Added ground stitching vias. Rerouted using arcs. Changed spacing to 12mil. Length matched within pairs. Increased inter pair clearance. Lots of stuff moved to accommodate this, inclu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
    [SFPP.PrjPCB, mezzanine.SchDoc, phy0.SchDoc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]
2011-06-23 updated output files post internal review
    [Bill of Materials-SFPP.csv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]
2011-08-04 Added filtering to SFP+ 3v3
    [SFPP.PrjPCB, phy0.SchDoc, phy1.SchDoc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]
2011-08-19 moved release to the right place
    [CX4 Mezz Card.ods, CX4 Mezz Card.xls, CX4 Mezz Card_Production.xls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]
2011-12-15 Update to CX4 BOM - 15/12/2011 P. Gibbs
    [CX4 Mezz Card.ods, CX4 Mezz Card.xls, CX4 Mezz Card_Production.xls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]
2011-12-15 csv CX4 BOM added - 15/12/2011 P. Gibbs
    [CX4 Mezz_Card.csv]
2012-02-07 corrected CSV bill of materials
    [SFPP rev0.csv]
2012-07-30 moving svn repo to github
    [Bill of Materials-SFPP.csv, Bill of Materials-SFPP.xlsx, CX4 Mezz_Card.csv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]
2012-08-13 added rev1 release files
    [SFPP.GBL, SFPP.GBO, SFPP.GBP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]
2012-08-13 added assembly drawings
2012-08-14 Added Bom
2012-09-17 Cleaned up duplicates
    [Bill of Materials-SFPP.csv, Bill of Materials-SFPP.xlsx, Copy of EQ-8V18701LA0.xls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]
2012-09-17 Cleaned up furthjer duplicates
    [CX4 Mezz_Card.csv, CX4 Mezz_Card.xlsx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]
2013-05-09 Repo cleanup. Removed .svn, added readme.
    [Bill of Materials-SFPP.csv, Bill of Materials-SFPP.xlsx, Copy of EQ-8V18701LA0.xls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]
2013-05-09 Cleanup.
    Added readme files
    Added .gitignore for .svn
    Reorganised CX4 and SFPP to have design and release subdirectories.
    [CX4_!.PcbDoc, CX4_3port_card.SchDoc, CX4_enable_logic.SchDoc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]
2013-05-23 Updated BOM
    Added discontinued and new parts.
    [SFPP_BOM.csv]
